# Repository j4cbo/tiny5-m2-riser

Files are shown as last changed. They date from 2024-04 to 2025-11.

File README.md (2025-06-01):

# Tiny5 M.2 Riser

This is a project I've been working on to create a custom riser board for Lenovo Tiny5
series (M920q/M920x/P330 Tiny) to support an additional two M.2 SSDs as well as a 10G Ethernet card.
It builds on badger707's excellent work investigating [PCIe bifurcation](https://github.com/badger707/m920q-pcie-bifurcation/)
and adding a [second M.2 slot](https://github.com/badger707/m920q-dual-NVME/) to these systems.

Fully loaded with this riser, an M920x can support four M.2 2280 M-key SSDs, as well as an additional PCI card,
a SATA boot SSD, and an M.2 2230 E-key module. It also provides a standard 12 volt fan header.

This works **only** with the M920q, M920x, and P330 Tiny. Other systems in the Tiny5 family do not support PCIe bifurcation.

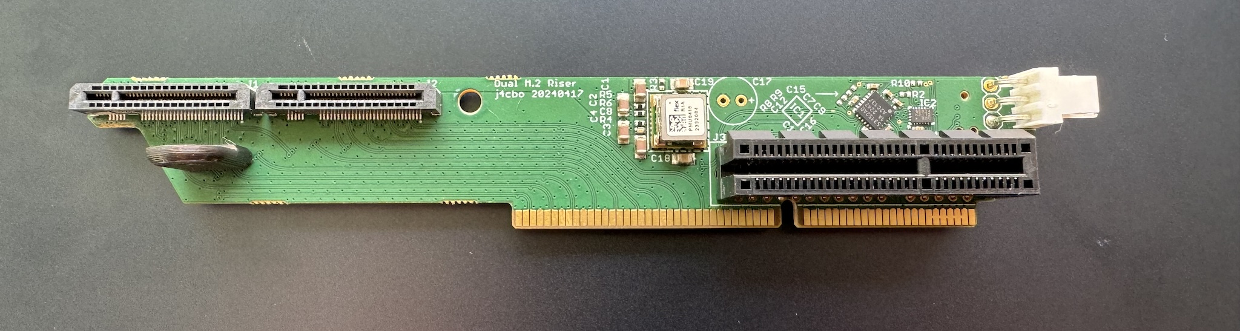
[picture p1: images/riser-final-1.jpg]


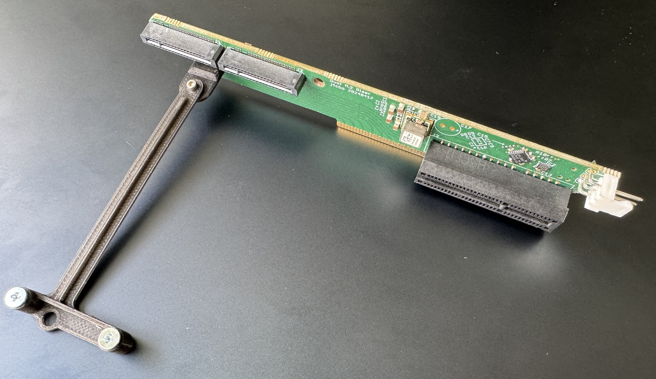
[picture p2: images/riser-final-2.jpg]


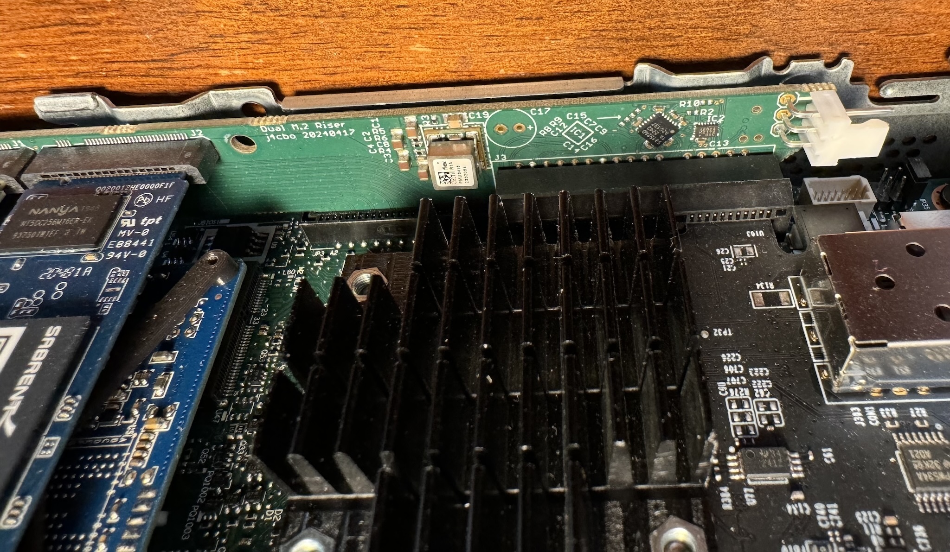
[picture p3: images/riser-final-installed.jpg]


Block diagram:
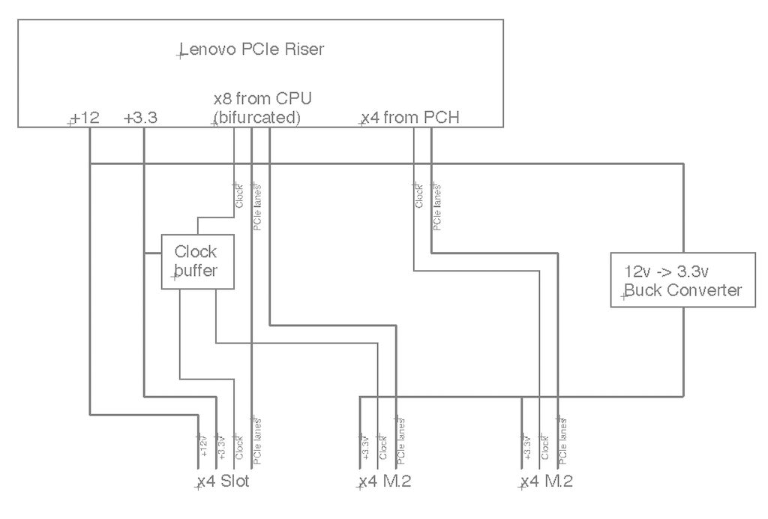
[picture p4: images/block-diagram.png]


According to the IQ3X0IL board schematics, the system +3V3 rail is rated for 9.74 amps, and is used for
various onboard components as well. A typical M.2 SSD is specified for 2.5 to 3.0 amps so four of them at
full load could exceed the power supply capacity. The riser board therefore uses a buck converter from
the +12V rail to avoid overloading the system +3V3 supply.

In addition to the power supply and clock buffer, a custom-programmed GreenPAK is used to handle
power sequencing and ancillary PCIe signals like PERST# and CLKREQ#.

As of 5/14/2024, I have a production batch of these and am now selling them, see issue #1.

Using this **requires soldering** two 0402 resistors on the motherboard to enable PCIe bifurcation.
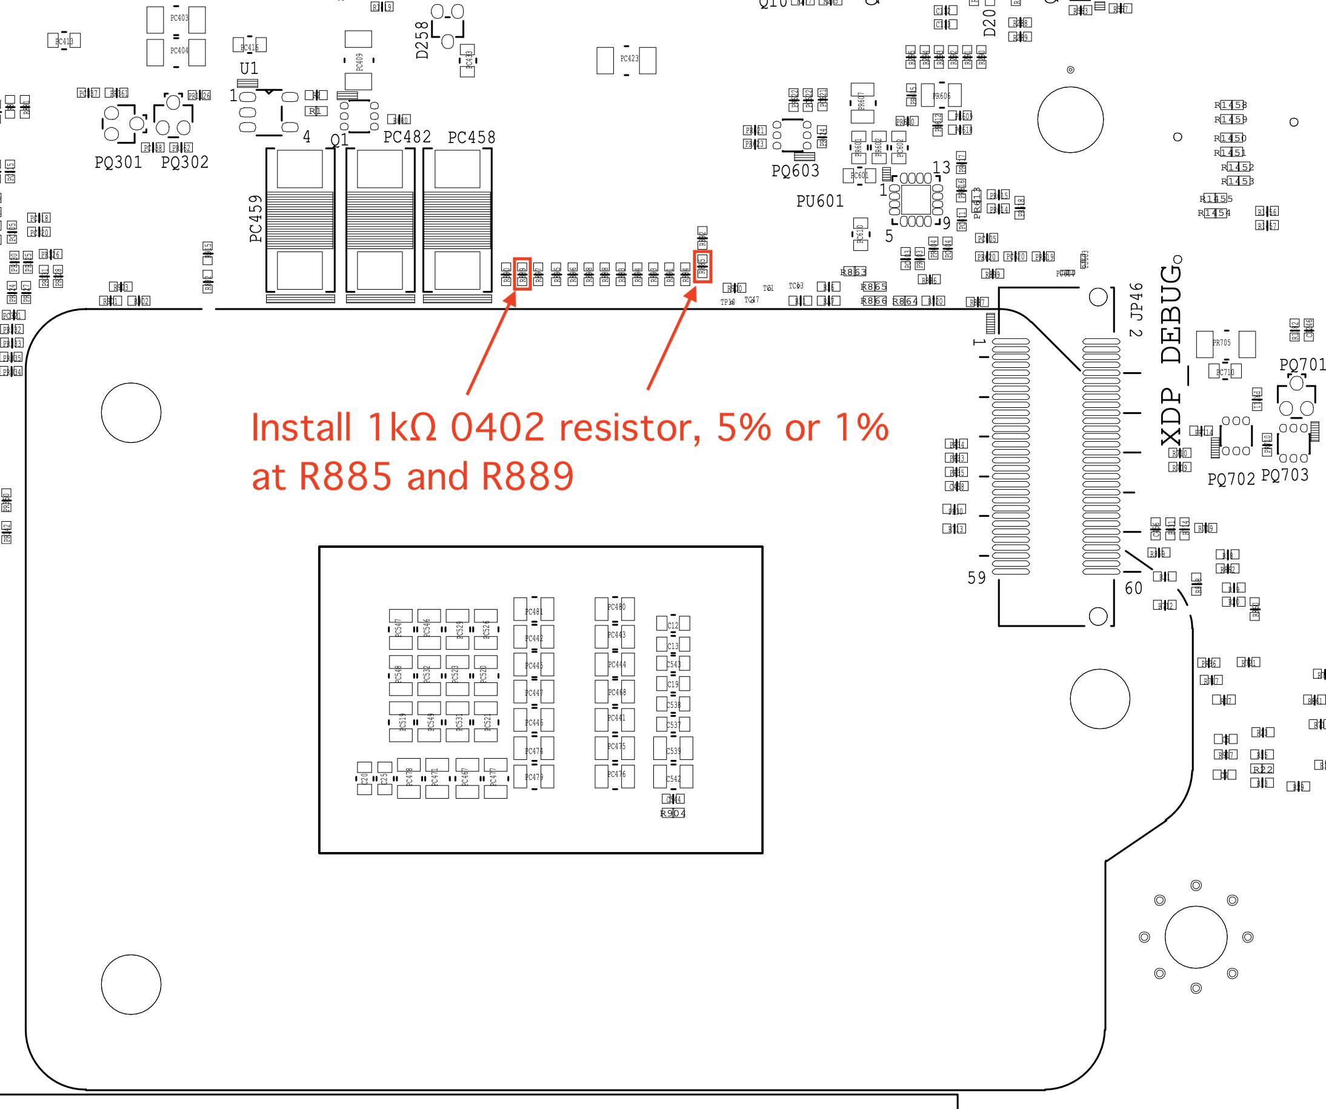
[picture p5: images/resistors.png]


## Mounting Bracket

There is also a mounting bracket to hold the additional M.2 drives in place. It replaces the WiFi antenna
support at the front of the case.

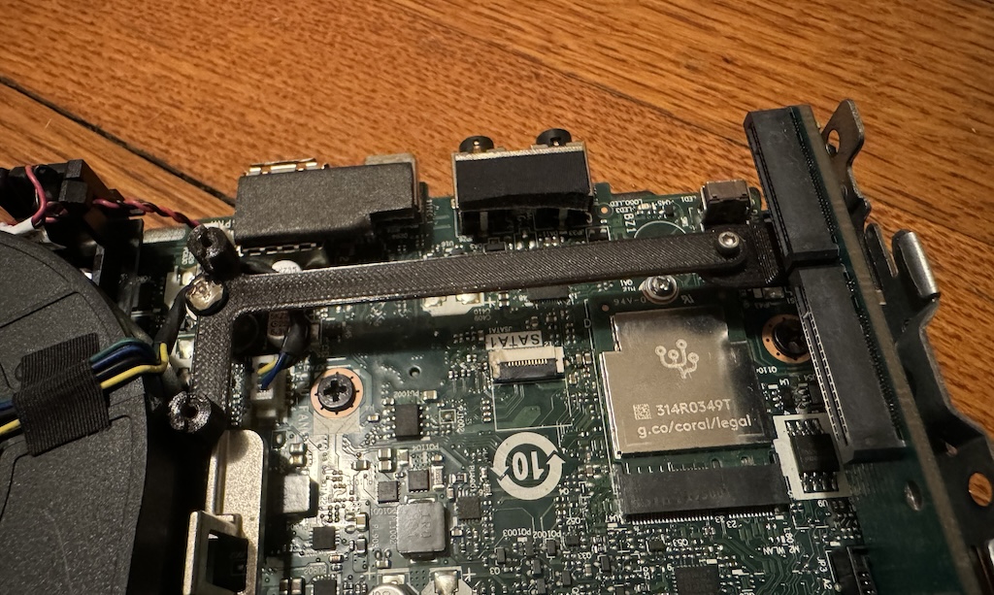
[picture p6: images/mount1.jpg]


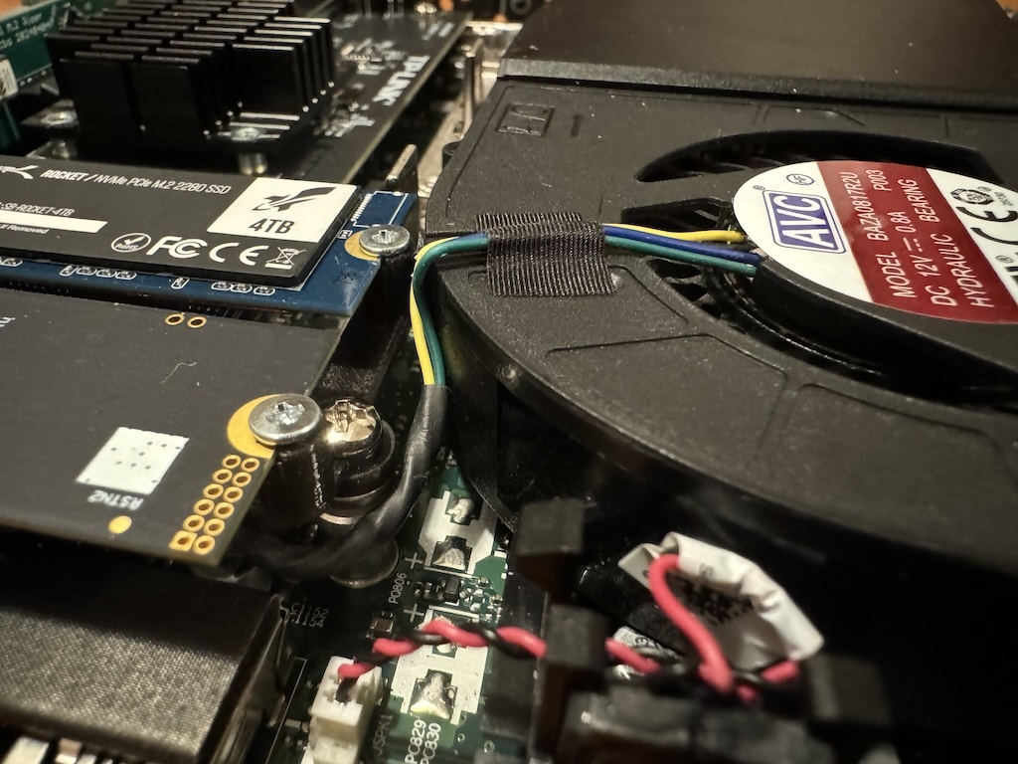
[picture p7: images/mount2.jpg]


## Disclaimer

This design is EXPERIMENTAL and provided WITHOUT WARRANTY. It has not been approved by Lenovo, the
FCC, or really anybody. I am not responsible if it breaks your computer, deletes your data, burns
down your house, or kicks your cat.

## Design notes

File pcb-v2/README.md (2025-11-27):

# Ordering Boards

The riser can be assembled by any PCB manufacturing contractor. I used [JLCPCB](https://jlcpcb.com/) and have optimized the parts list for their process. To order your own batch:

- Log in to your account (or create a new one, if you don't already have one).
- Upload `riser-v2.zip` with the "Add gerber file" box on the home page.
- Some properties of the PCB (4 layers, outside dimensions) will be auto-detected, but you will need to change several options:
  - Surface Finish: **ENIG**
  - Layer Stackup: **JLC04161H-7628** (this is critical for the PCIe bus to work!)
  - Impedance Control: **Yes**
    - Select +-10% option (Excel template is included in Gerber zip)
  - Mark on PCB: **Order Number (Specify Position)**
  - Gold Fingers: **Yes**
  - 30° finger chamfered: **No** 
- Check the "PCB Assembly" box and make sure these options are selected:
  - PCBA Type: **Standard** (Economic not available)
  - Assembly Side: **Top Side**
  - Edge Rails/Fiducials: **Added by JLCPCB**
  - Parts Selection: **By Customer**
  - PCBA Qty: although JLC will manufacture PCBs only in multiples of 5, you can choose to have them solder parts onto as few as 2 of them - but doing so usually doesn't save much money.
- Click "Next". Make sure the top side of the PCB is selected, and click "Next" again.
- Upload `riser-v2_top_bom.csv` and `riser-v2_top_cpl.csv`.
- At this point you should see a parts list showing which parts are in stock and which are out of stock. Most likely, the `SI53152-A01AGMR` clock buffer chip and `MDT350M01001VT` right-angle M.2 connector will be out of stock, so you'll need to use JLCPCB's global sourcing tool to order them. If any other parts are out of stock, note those as well.
- If parts are out of stock, you can click "next", choose "Do not place", and "next" again to see what the cost would be excluding the missing parts. Don't actually check out with missing parts, unless you're willing to buy and solder them yourself. If you're just getting an estimate, don't worry about the component placements being just right.
- Go to the [JLCPCB Parts Manager](https://jlcpcb.com/user-center/smtPrivateLibrary/myPartsLib) and click "Global Sourcing Parts".
  - For the clock buffer, search for either `SI53152-A01AGM` or `SI53152-A01AGMR` (these are equivalent parts). Find a supplier with an MOQ (minumum order quantity) less than the number of risers you're making and click "add".
  - Repeat for any other out-of-stock parts.
- Click "Parts Cart" on the left-hand sidebar and make sure "Global Sourcing Parts" near the top is selected. You should see the parts you added. Then check out. What you are doing in this step is paying JLCPCB to source and store those parts for your future order. It usually takes a few weeks for them to arrive, and you'll get an email when that happens.
- Once the parts you ordered are available, repeat the whole process from the top. **Make sure to choose the right Impedance Control and Layer Stackup options if you're starting over.**
- At the "Component Placements" step, click "Select all top parts" and use the arrow keys to move the parts so that they line up with the pads on the board. You can rotate parts 90 degrees at a time with the spacebar.
  - All the R, C, and L parts are symmetric - there's no such thing as the wrong way around.
  - The pins of J4 should be sticking off in space past the end of the board, away from all the other components.
  - Make sure the white circle on IC1 and IC2 is near the corresponding white circle on the PCB.
  - The "out" pin of Y1 should be on the top left side, near the white "Y1" text on the PCB.
  - The + side of D1 should be down towards the PCIe slot.
- Finally, click "save to cart" and check out.

If you use another manufacturer, give them the following PCB specifications:
- Controlled impedance
- Coplanar differential pair (on L1 referenced to L2, and on L4 referenced to L3) of 85 ohms nominal, +/- 10 ohms
- ENIG surface finish with gold fingers
- No chamfer

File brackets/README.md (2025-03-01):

These are the STL files for the dual M.2 riser. They can also be [exported directly from OnShape](https://cad.onshape.com/documents/99f2719df4fededdfde5e0b6/w/fa3fefc0be67ea79d0f2b093/e/995a9ee69cf62af61cb02c70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).

You will also need:
- Three M1.6 x 5mm screws
- Two M2 x 2.5mm screws, with large flat heads suitable for securing the M.2 SSDs

To assemble the risers:

1. Print one copy of each file (`m2-mount` [see options below], `pcb-angle`, `spacer`). I use PLA with the default PrusaSlicer settings, 0.1 mm layer height for `spacer` and 0.2mm for the other files.
2. Use an M1.6 screw to "pre-tap" each of the three holes in the pcb-angle part. This will make the rest of assembly much easier.
3. Using the `spacer` on the back of the PCB with the bridge portion away from the PCB, assemble `spacer` and `pcb-angle` as shown. It is important that the screw heads not come directly into contact with the PCB, because there are signal traces very close to the holes.
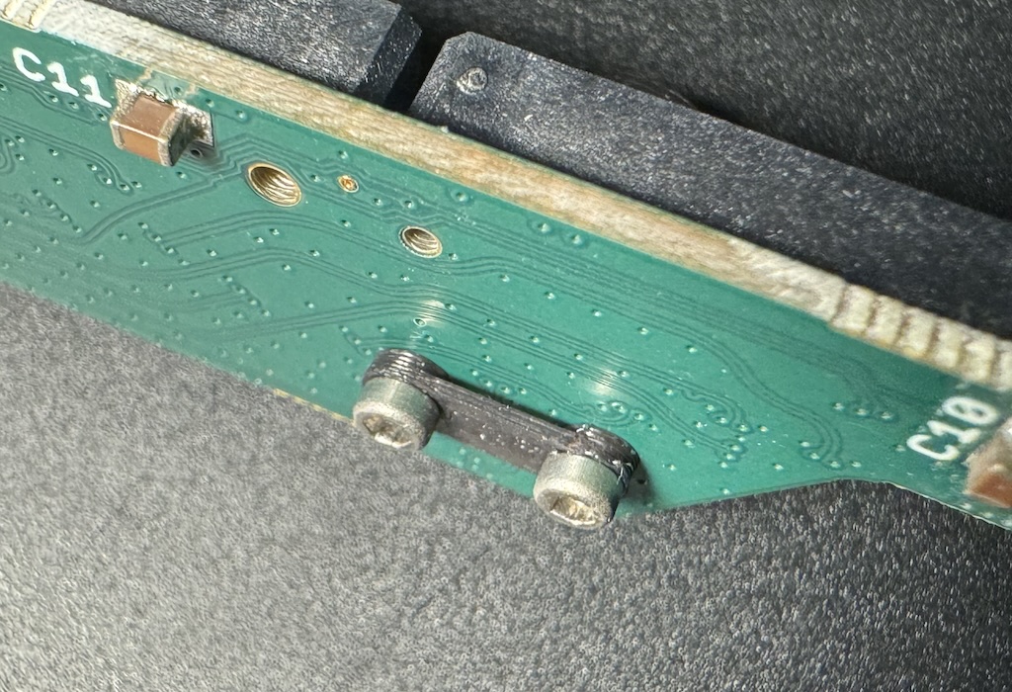
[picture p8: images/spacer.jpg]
   
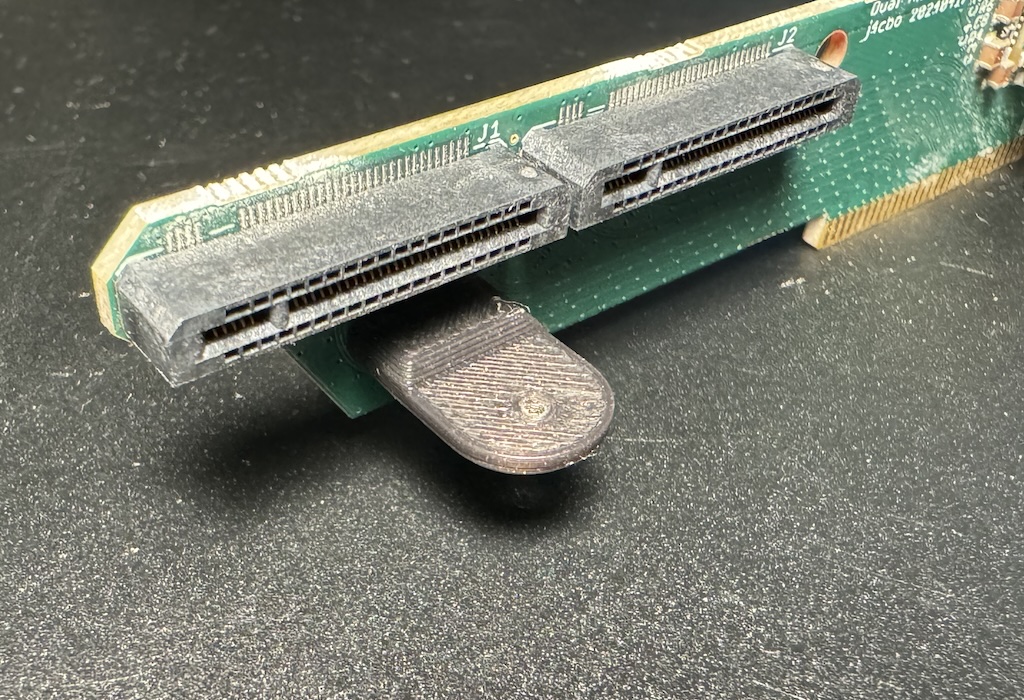
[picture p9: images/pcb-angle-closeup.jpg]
   
5. Attach `m2-mount` to the flat portion of `pcb-angle`.
   
5. Remove the internal WiFi bracket from your M920q and install the riser board assembly. Use the existing standoff and screw to retain the opposite end of the `pcb-angle` part.
6. Install the SSDs and PCIe card. Enjoy your extra storage!

### Mount Options

| STL-File | Option | Image |
| --- | --- | --- |
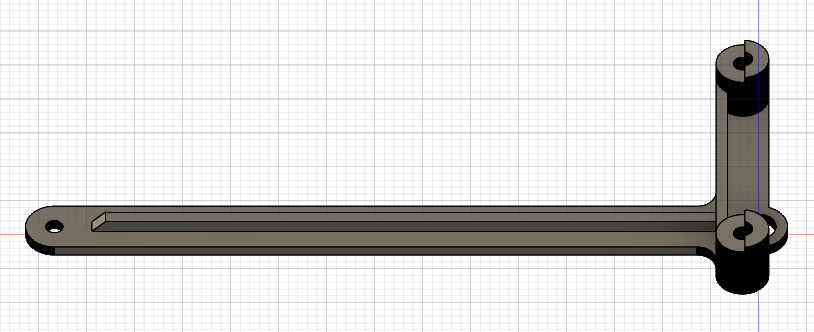
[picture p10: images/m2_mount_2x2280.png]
|`m2-mount`|2280 + 2280||
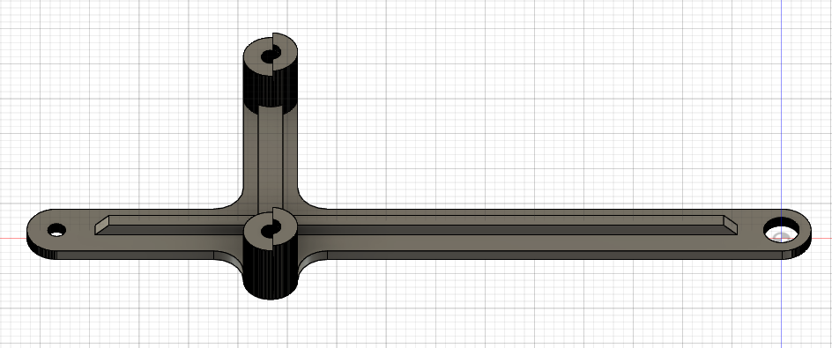
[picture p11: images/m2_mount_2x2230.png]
|`m2-mount_2x2230`|2230 + 2230||
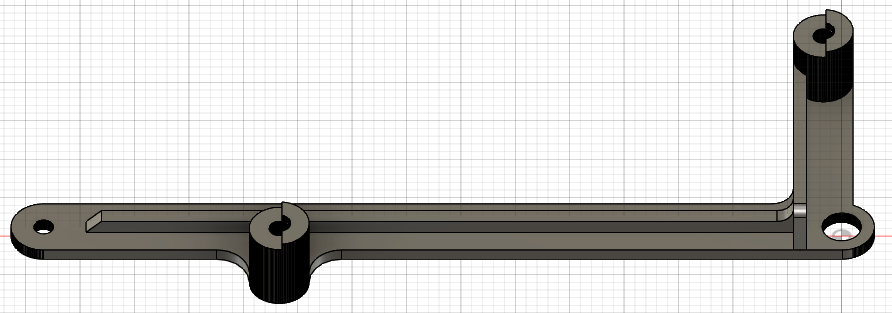
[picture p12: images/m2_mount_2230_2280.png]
|`m2-mount_2230_2280`|2280 + 2230||

**Example 2230+2280**
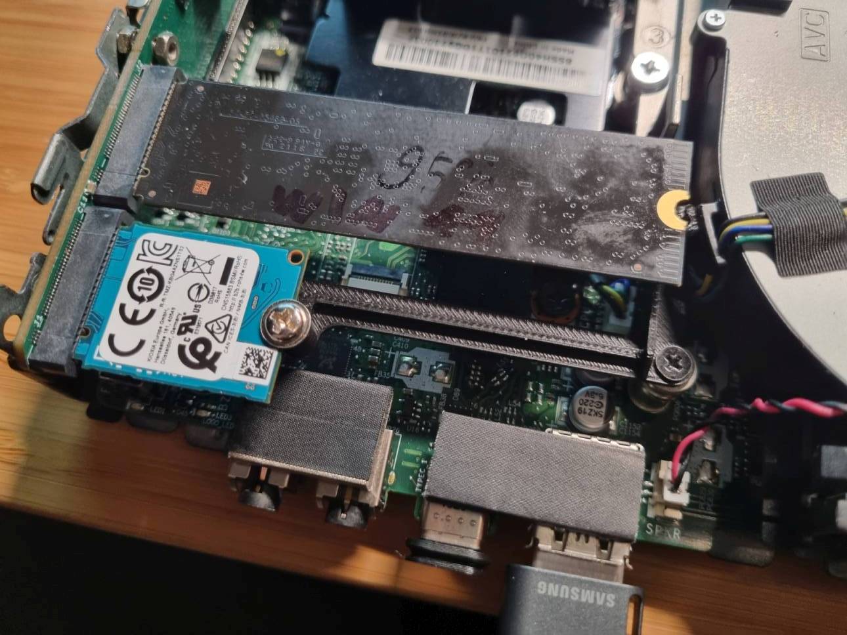
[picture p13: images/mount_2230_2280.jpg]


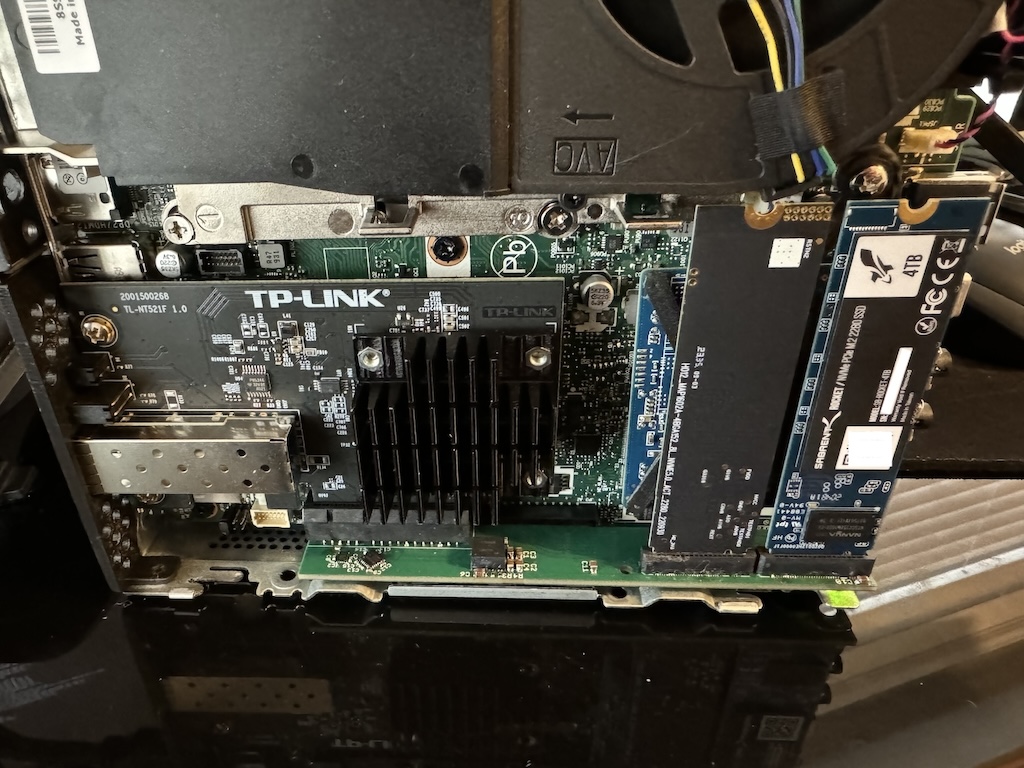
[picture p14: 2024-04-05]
images/prototype1.jpg

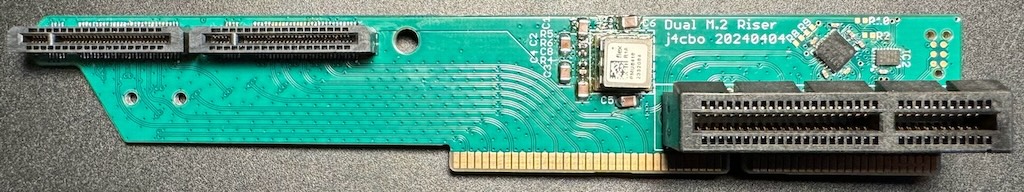
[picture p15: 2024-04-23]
images/prototype2.jpg

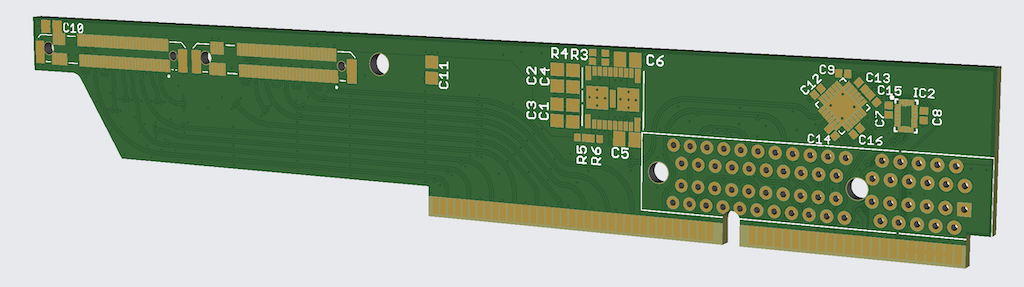
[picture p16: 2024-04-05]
images/prototype1-pcb.png

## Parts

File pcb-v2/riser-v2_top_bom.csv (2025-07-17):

Comment | Designator | Footprint | JLPCB Part #
0.1uF | C7 C9 C12 C13 C14 C15 C16 C20 | C0402 | C1525
1N5819 | D1 | SOD323-R | C191023
1uF | C1 | C0402 | C52923
2.2k | R3 R6 | R0402 | C25879
2N7002 | T1 | SOT23-3 | C8545
10k | R2 R5 R7 R8 | R0402 | C25744
10uF 10V | C10 C11 | C0603 | C19702
10uF 25V | C21 C22 C23 | C1206 | C13585
47uF 10V | C2 C3 C4 | C1206 | C96123
0022053031 | J4 | 1X03 | C706940
ECS-327KE-TR | Y1 | OSC_ECS-327KE-TR | C5280579
MDT350M01001VTEXT | J1 J2 | MDT350M01001VT_EXT | C722526
PCI-E-X4 | J3 | PCI-E-X4 | C2926855
SI53152-A01AGM | IC1 | QFN24_4X4_SIL | C2651396
TPS51386RJNR | IC2 | VREG_TPS51386RJNR | C22388893
XAL7070-182MEC | L1 | DFN750X725X700-2N | C3911679

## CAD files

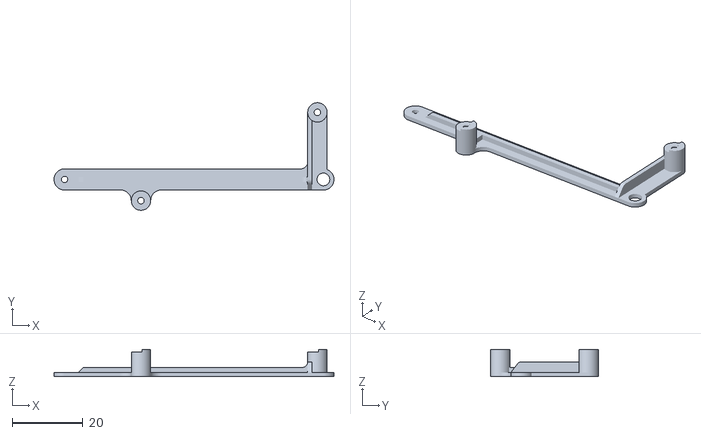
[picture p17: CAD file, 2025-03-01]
brackets/m2-mount_2230_2280.stl
79.4 x 30.5 x 7.70

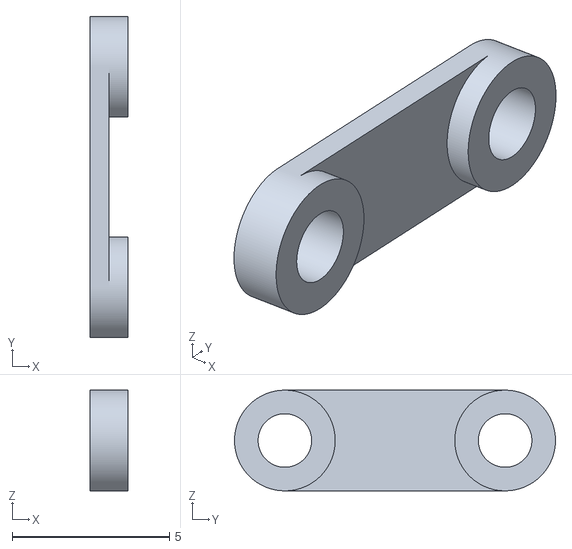
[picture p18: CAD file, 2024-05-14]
brackets/spacer.stl
1.20 x 10.2 x 3.20

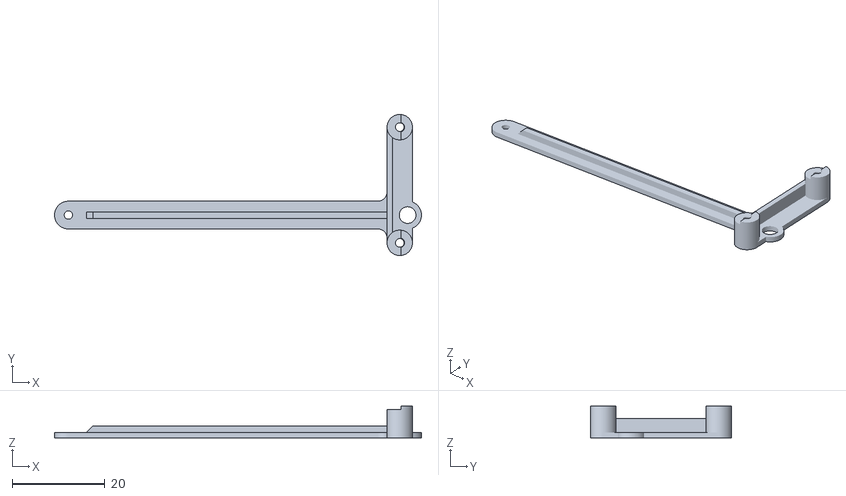
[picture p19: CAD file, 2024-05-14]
brackets/m2-mount.stl
79.4 x 30.5 x 6.90

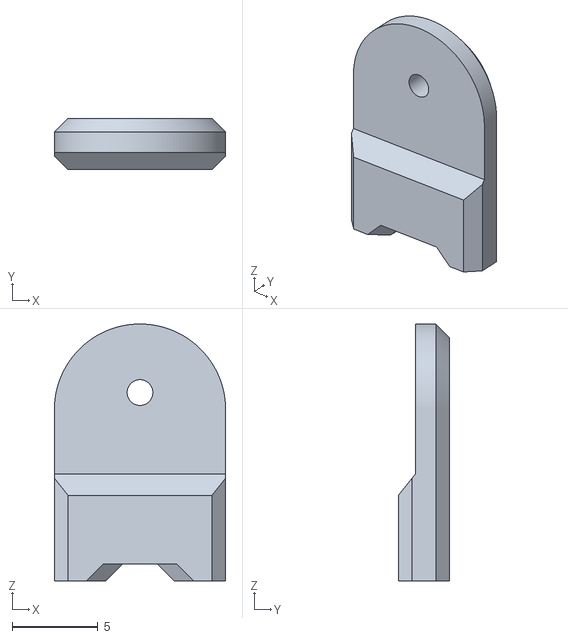
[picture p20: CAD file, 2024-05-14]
brackets/pcb-angle.stl
10.0 x 3.00 x 15.0

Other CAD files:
brackets/m2-mount_2x2230.stl

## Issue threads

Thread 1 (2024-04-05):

Group buy interest?

j4cbo, 2024-04-05:
A few people have mentioned interest in buying one of these so I'm starting a thread to discuss. Price will be $50 each plus shipping.

galvesribeiro, 2024-04-05:
Hello! I do want one. Sign me in! :)

kitor, 2024-04-06:
I'd build one myself so I'm interested in either bare pcbs or project files.

struthio, 2024-04-07:
hi, I am interested in final product or bare pcbs. I have also 2 questions:
1. When final price will be known ?
2. What is price for shipping ? I saw You are located in USA, so shipping to Europe might be pricey (compared to price of adapter).

marcojk, 2024-04-08:
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

Same here, possibly an Europe-based group buy could be set up.
Opening the design would be nice too!

systemerror-codenotfound, 2024-04-08:
Hi,
It would be possible to try an develop a version for the M910X ?

I'm part of a group here on spain that would be really interested im several parts

skruje, 2024-04-09:
I'd probably be in for 1-3 of these once you're satisfied with the prototypes, depending on the pricing.

Will the custom riser still require all the SMD soldering on the motherboard shown in badger707/m920q-dual-NVME?

Nice to haves for future revs:
- option for an x8 port for shorter cards like the AOC-STGN-I2S. Maybe a jumper to select x8x4 or x4x4x4. If not practical electrically, an x8 slot wired for x4, or just one with an ["open" end](https://upload.wikimedia.org/wikipedia/commons/a/a3/PCIe_J1900_SoC_ITX_Mainboard_IMG_1820.JPG) would be more flexible at similar cost.
- 12V (~0.1A) fan header for cooling hotter cards without additional soldering

kitor, 2024-04-09:
> Hi, It would be possible to try an develop a version for the M910X ?

@systemerror-codenotfound Why don't you start own issue instead of hijacking non-related one?

> Will the custom riser still require all the SMD soldering on the motherboard shown in [badger707/m920q-dual-NVME](https://github.com/badger707/m920q-dual-NVME/)?

@skruje No, you are confusing two different mods. This one requires bifurcation mod which is two resistors change from [badger707/m920q-pcie-bifurcation/issues/1]

If you use both, you can go crazy and have up to 6 NVME drives in this computer. One in existing slot, one in dual nvme mod, three using riser we discuss here and one extra in WiFi slot (but that will work as PCIe x1) :)

> option for an x8 port for shorter cards like the AOC-STGN-I2S. Maybe a jumper to select x8x4 or x4x4x4.

This was already answered in badger707 thread. It is impossible, not impractical, due to a few factors:

* you can't "switch" where 4 pairs of signals go with a single jumper
  * switching between bifurcated and non-bifurcated slot is done via modding the motherboard - you change cpu configuration resistors for that.
  * in modified state, PCIe lanes are out of order and this riser corrects for that
  * thus in unmodified (x8) state lanes would be out of order again and nothing would work
* you could try wire up signals to both one of NVME m.2 slots and PCIe slot, but this fails quickly:
  * out of order problem from above
  * even if not, signal reflections would be the issue (considering lanes connected to both slots)
  * and in that hypothetical / impossible situation you would still need to select x8+m.2 or x4 + dual m.2 by soldering proper slots into your riser and selecting resistors on the board.

Open end slot seems a good idea on the first glance (but you can also mod your slot very easily with craft knife). However from the photos I'm not sure if x8 card would even fit - I'm under impression that first m.2 slot would interfere anyway.

j4cbo, 2024-04-09:
The way I think of it, https://github.com/badger707/m920q-dual-NVME turns an m920q into roughly an m920x, which has two onboard M.2 connectors for NVMe SSDs. Then my board in conjunction with the two resistors changed in https://github.com/badger707/m920q-pcie-bifurcation adds two more M.2s (one off the PCH, one off the bifurcated CPU port) and provides a PCIe x4 slot. As @kitor says, if you aren’t using the slot for a network card, then (with a PCIe x4 to M.2 board) you could add another SSD there, and if you aren't using the WiFi M.2 you could (with an A+E-key to M-key adapter) add yet another SSD there, albeit with only one PCIe lane.

There's about 10mm vertically between the M.2 connectors and the x4 slot on my board, so a PCIe card that extends under the M.2 SSDs would be fine as long as it didn't have a large heatsink.

j4cbo, 2024-04-10:
Update: price for the first batch will be $70 USD each plus shipping, and I expect them to be available in mid-May. There will also be a 12V fan header on the board with the standard 3-pin PC fan pinout. This is for m920q/m920x only. The m720q doesn't support bifurcation, and the m910 series has a different pinout and lacks the additional 4 PCH lanes on the socket. (A single-M.2 m720q variant is in the works, though.)

Shipping will be about $5 within the US. Internationally, slow shipping (1-4 weeks) is about $25, or by UPS about $40. It might make sense for me to ship a bunch to someone in Europe for further distribution from there.

skruje, 2024-04-10:
Love that @j4cbo managed to get a fan header in there. I'm out for now; hoping we can find a more economical way to deliver to Canada for future batches. Any chance the design will be open sourced?

j4cbo, 2024-04-10:
Canada shipping is cheaper than Europe - I edited the post above with those prices and quantity discounts. I'm not opposed to open-sourcing the design but, selfishly, I'd like to make back what I spent on the first batch first :)

chocmake, 2024-04-11:
> This is for m920q/m920x only. The m720q doesn't support bifurcation

Just to clarify, badger's bifurcation repo states compatibility for M720q. Is something different for this riser or am I missing something?

j4cbo, 2024-04-11:
> Just to clarify, badger's bifurcation repo states compatibility for M720q. Is something different for this riser or am I missing something?

It's mentioned in the README, but there's a good argument as to why bifurcation wouldn't work on the m720q here: https://github.com/badger707/m920q-pcie-bifurcation/issues/2#issuecomment-1835940720

The m720q does still have the extra 4 lanes from the PCH, though, which should support a single M.2.

j4cbo, 2024-04-18:
I have one prototype available which I'm offering for free (within the US) if anyone wants to beta test. It lacks the fan header and open-back PCIe slot that the production ones will have (probably a month out), and it's not pretty, but I've tested in my own server and it is working well. My email is on my Github profile.

galvesribeiro, 2024-04-18:
Would test for you but I'm in Brazil :P

j4cbo, 2024-04-19:
Update: I've placed the production order :) I was able to get the price down to $50. The production boards will include an open-backed PCIe slot and a 12V fan header, and will be ready in about a month.

galvesribeiro, 2024-04-19:
Looking forward for it :)

struthio, 2024-04-19:
@j4cbo $50 for M920Q one ? (2x NVME + 1xPCIe for Ethernet) ? If Yes then I even consider getting 2.
Are You taking any pre-orders ?

galvesribeiro, 2024-04-19:
Yeah, rephrasing, I want 2 as well 😄

@j4cbo if you can send email and/or PayPal/Wise or whatever way you decide to be paid, we can put the pre-order ahead.

j4cbo, 2024-04-21:
To pre-order, send me an email - my email address is shown on my main Github profile :)

galvesribeiro, 2024-04-21:
Done :shipit:

struthio, 2024-04-22:
> I'm not opposed to open-sourcing the design but, selfishly, I'd like to make back what I spent on the first batch first :)

Maybe then, add project files as a documentation to bought boards or something like that ?

j4cbo, 2024-04-29:
Just an update here, the manufacturer has finished fabricating the bare PCBs and is now preparing for assembly. Still looking like I'll have them by the end of May.

mdronald, 2024-05-01:
> Just an update here, the manufacturer has finished fabricating the bare PCBs and is now preparing for assembly. Still looking like I'll have them by the end of May.

I'm interested in buying one or two but I've the m920q model. Would I have to mod it using [badger707](https://github.com/badger707/m920q-dual-NVME/commits?author=badger707) guide to work as a m920x before using your riser?
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
j4cbo, 2024-06-14:
Thanks for all the info! In my own system I'm currently running TrueNAS SCALE on bare metal, but I had been thinking of putting a Proxmox layer underneath. (TrueNAS works well enough as a VM host but Proxmox is much more powerful.) It's interesting that there's an interaction between passthrough and bifurcation, not terribly surprising but it seems like it "should" work.

I'm now sold out of the first batch of 20 boards! I'll ask the manufacturer about pricing for a follow-up batch. Anyone else who's interested in buying one, please let me know.

Go0oSer, 2024-06-19:
Are these still available?  Id be interested in 2 if so.

j4cbo, 2024-06-20:
Update: I've ordered more boards! :) I'll reach out to everyone who's contacted me once they're ready to ship.

joseal, 2024-06-24:
Hi @j4cbo, please count with me for one more board to EU. If there is anyone else interested in EU, I don't mind to join for a group buy.

thank you!

marcojk, 2024-06-24:
> > I wonder where @j4cbo ordered the first batch. Maybe it would be just cheaper to order a second batch directly to someone in EU ... assuming there's enough interest of course.
>
> This is the option i was referring to. Collect the order, pay to j4cbo, order shipped directly to europe and from here we will manage somehow :)

I'd be interested in 2 boards, and I still believe this could me an interesting alternative...

AndrewL82, 2024-06-26:
Hey, I'd be interested in buying 2 if shipping to Australia isn't too much :)

su-thomas, 2024-06-27:
> Hey, I'd be interested in buying 2 if shipping to Australia isn't too much :)

@AndrewL82 I'm also interested in Australia, perhaps we can bundle shipping to save on costs

randlor, 2024-07-28:
Hi, in the UK and interested in one. Thanks.

wouterbouvy, 2024-08-02:
Awesome work @j4cbo! I would be interested in buying 3 or 6 of your risers once your new batch arrives. Shipment to the EU.

j4cbo, 2024-08-02:
The new batch is here! :) Send me an email if you haven't already.

lmbacelar, 2024-08-26:
Hi. Are  you still selling these?
I am interested in +3 boards delivered in EU.

mvnixon, 2024-08-27:
Hi, I sent you an email, not sure if you received it, I am after 2 delivered to the EU. Thanks

j4cbo, 2024-08-27:
@lmbacelar - yep, still available! Send me an email, my address is on my Github profile.
@mvnixon - just replied to your email

j4cbo, 2025-01-18:
Closing this now. I'm not planning on making any more, but all the files necessary for someone else to order a batch from JLCPCB are in the repository - happy to walk anyone through the process if they're interested in doing so.

evil2k2, 2025-01-18:
> Closing this now. I'm not planning on making any more, but all the files necessary for someone else to order a batch from JLCPCB are in the repository - happy to walk anyone through the process if they're interested in doing so.

Can you give some information about manufacturing?
And also how you programmed the green pack.
Thanks for the great work
Do you plan to work in newer machines like p350 or 360/P3 tiny?

j4cbo, 2025-01-18:
> Can you give some information about manufacturing? And also how you programmed the green pack. Thanks for the great work Do you plan to work in newer machines like p350 or 360/P3 tiny?

I uploaded a description of how to order here: https://github.com/j4cbo/tiny5-m2-riser/tree/main/pcb-v2

The new rev doesn't require any programming, but for the old one, I used an SLG4DVKDIP dev board and a Tag-Connect cable to flash the Greenpak parts.

No plans to design for newer machines, since the M920 is the only one I have :)

Closed 2025-01-18.

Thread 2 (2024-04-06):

Why you use a buck converter and aren't the nvme drives overheating??

systemerror-codenotfound, 2024-04-06:
Just take 3.3V from the X4 slot and use it

Also, those drives need some cooling no?
aren't them overheating?

I have a 3d printable lid that can use a 120mm fan but it's pretty big
https://www.printables.com/es/model/603074-lenovo-tiny-m910q-top-cover-mods

galvesribeiro, 2024-04-06:
He already explained why he did that [here](https://github.com/badger707/m920q-pcie-bifurcation/issues/1#issuecomment-2035056651).

j4cbo, 2024-04-06:
I've added some current numbers to the README. As for temperature, the highest I saw during an extended ZFS resilver was 67°C which is within spec.

Closed 2024-04-06.

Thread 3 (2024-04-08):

Adapt this mod to M910X

systemerror-codenotfound, 2024-04-08:
The diagram for M910X should be similar to this, this is from a M710Q as i couldn't find one for the M910X
https://images.boosty.to/image/e28a63ee-ad04-4562-828a-b6a58697e4db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

And this is the one for the M920Q
https://cxema.su/_sh/37/3745.jpg

and the Q270 in m910x chipset support the same bifurcation as the M920q

https://www.intel.la/content/www/xl/es/products/sku/98088/intel-q270-chipset/specifications.html

1x16 or 2x8 or 1x8+2x4

If i'n not wrong, right now you are getting 3 x4 pci ports from the actual PCI, 2 by bifurcating the PCI in 2 x4 and one x4 from the chipset
As per other comment in the @badger707 repo the pads are almost exactly the same and somebody actually tried to bifurcate it and it appear as 2 x4 lines and 1 x4 line, so the bifurcation on the CPU side works

j4cbo, 2024-04-09:
So, the main difference between my mod and https://github.com/badger707/m920q-pcie-bifurcation is that the M720/M920 series route an additional 4 lanes from the PCH to the riser slot, in addition to the 8 lanes from the CPU. Looking at the schematics for the IQ270IH1 (m710/m910/P320), it looks like the pinout is different and the extra 4 lanes aren't there:

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

I think https://github.com/badger707/m920q-pcie-bifurcation/issues/3 is the issue describing what you're looking for?

systemerror-codenotfound, 2024-04-26:
Okay,
it's working on the m910x, i have to make some tests but i'm able to use both nvme's

The weird part is that i'm seeing another x8 pci bus

zzs95, 2024-04-26:
> the original comment was made by @zzs95

> it's working on the m910x, i have to make some tests but i'm able to use both nvme's

Thank you very much for your verification. I wondered if there was something wrong with my machine, so that I didn't make it.

I am more inclined to think that there is no 4x pcie from PCH on the m910x machine, because there is no 4x riser in the [accessory library](https://pcsupport.lenovo.com/us/en/products/desktops-and-all-in-ones/thinkcentre-m-series-desktops/thinkcentre-m910x/10my/parts/display/compatible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) Later models m920x and p340 tiny (m90q gen1) have this accessory.

m920x (01AJ929):
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

m90q gen1(5C50W00876):
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

j4cbo, 2024-04-26:
I think this discussion probably belongs over on https://github.com/badger707/m920q-pcie-bifurcation ? The riser I designed to allow putting three separate PCIe devices (two M.2s and an x4 slot) isn't possible because there's no routing from the PCH to the expansion slot - but bifurcation _does_ work on the 910 series.

galvesribeiro, 2024-04-26:
> Okay, it's working on the m910x, i have to make some tests but i'm able to use both nvme's
>
> The weird part is that i'm seeing another x8 pci bus

After doing the PCIe bifurcation mode, add the "official" riser, it got me an extra x8 controller as well (x16, x8, x4):

```
[root@yoda:~] lspci
0000:00:00.0 Host bridge: Intel Corporation 8th Gen Core Processor Host Bridge/DRAM Registers
0000:00:01.0 PCI bridge: Intel Corporation 6th-10th Gen Core Processor PCIe Controller (x16)
0000:00:01.1 PCI bridge: Intel Corporation Xeon E3-1200 v5/E3-1500 v5/6th Gen Core Processor PCIe Controller (x8)
0000:00:01.2 PCI bridge: Intel Corporation Xeon E3-1200 v5/E3-1500 v5/6th Gen Core Processor PCIe Controller (x4)
0000:00:02.0 VGA compatible controller: Intel Corporation CoffeeLake-S GT2 [UHD Graphics 630]
0000:00:08.0 System peripheral: Intel Corporation Xeon E3-1200 v5/v6 / E3-1500 v5 / 6th/7th/8th Gen Core Processor Gaussian Mixture Model
0000:00:14.0 USB controller: Intel Corporation Cannon Lake PCH USB 3.1 xHCI Host Controller
0000:00:14.2 RAM memory: Intel Corporation Cannon Lake PCH Shared SRAM
0000:00:16.0 Communication controller: Intel Corporation Cannon Lake PCH HECI Controller
0000:00:16.3 Serial controller: Intel Corporation Cannon Lake PCH Active Management Technology - SOL
0000:00:17.0 SATA controller: Intel Corporation Cannon Lake PCH-H AHCI Controller
0000:00:1b.0 PCI bridge: Intel Corporation Cannon Lake PCH PCI Express Root Port #17
0000:00:1b.4 PCI bridge: Intel Corporation Cannon Lake PCH PCI Express Root Port #21
0000:00:1c.0 PCI bridge: Intel Corporation Cannon Lake PCH PCI Express Root Port #6
0000:00:1f.0 ISA bridge: Intel Corporation Q370 Chipset LPC/eSPI Controller
0000:00:1f.3 Audio device: Intel Corporation Cannon Lake PCH cAVS
0000:00:1f.4 SMBus: Intel Corporation Cannon Lake PCH SMBus Controller
0000:00:1f.5 Serial bus controller: Intel Corporation Cannon Lake PCH SPI Controller
0000:00:1f.6 Ethernet controller: Intel Corporation Ethernet Connection (7) I219-LM
0000:02:00.0 Non-Volatile memory controller: Samsung Electronics Co Ltd NVMe SSD Controller PM9A1/PM9A3/980PRO
0000:03:00.0 Non-Volatile memory controller: Samsung Electronics Co Ltd NVMe SSD Controller PM9A1/PM9A3/980PRO
0000:04:00.0 Non-Volatile memory controller: Samsung Electronics Co Ltd NVMe SSD Controller PM9A1/PM9A3/980PRO
0000:05:00.0 Non-Volatile memory controller: Samsung Electronics Co Ltd NVMe SSD Controller PM9A1/PM9A3/980PRO
0000:06:00.0 Non-Volatile memory controller: Phison Electronics Corporation PS5013 E13 NVMe Controller
```

With that, I can put the two NVMe M.2 there and it just work. As you can see on `lspci` I have 4 Samsung 980 PRO there and they all work just fine (The Phison is a 2230 M.2 NVMe on the Wifi slot).

With @j4cbo Riser I will be able to use the other extra 4 lanes from the PCH and use along with the two M.2 a dual 10G NIC.

But yeah, you should go post on the other repo where you can get more help about the PCIe mod.

Closed 2024-05-03.

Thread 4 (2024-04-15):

[Suggestion] Use PCIe x16 connector

galvesribeiro, 2024-04-15:
On the prototype picture I see a x4 connector for the PCIe card.

Would it be possible to use a x16 connector with only x4 wired? The reason I'm asking is so we can easily use bigger cards using the same riser.

I know we can use an open-ended PCIe connector but those are harder to find for manufacture as they are not safer because leave the card connections "out".

I hope you consider the suggestion.

Thanks!

j4cbo, 2024-04-15:
An x16 connector won't fit because the space where the pins would go is needed for the signal traces to the M.2 connectors. However, I think I can source an open-back connector...

galvesribeiro, 2024-04-15:
Ok. Duck tape on the open connectors it is 😄

j4cbo, 2024-04-15:
If you want it to look nice and professional, pick up some Kapton tape :)

Closed 2024-04-15.

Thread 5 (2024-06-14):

Is this compatible with the P330 Tiny?

rohankapoorcom, 2024-06-14:
Do you know if this will work with the P330 tiny? My understanding is that the P330 tiny is close to the M920x since it has dual NVMe slots on the board already.

j4cbo, 2024-06-14:
I haven't tried one but I would expect so - it's the same IQ3X0IL motherboard and Q370 chipset as the M920x/M920q.

rohankapoorcom, 2024-06-17:
Cool - if you do another batch, I would be interested in picking up a few of them (at least 1, up to 3 or 4 assuming it works out with the P330).

CodyBohn, 2025-07-17:
I would also be interested in multiple from another batch

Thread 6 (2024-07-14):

Showcase riser working

galvesribeiro, 2024-07-14:
I just wanna share with others that I have full success using this riser.

I have 4x Samsung 980 Pro 2TB (two in the riser itself and two in the back), one M.2 on the Wifi slot (Phison on the screenshot) and a dual 25Gb Mellanox Connect-X 4 NIC, and another SATA SSD.

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

Thanks @j4cbo for the amazing work!

galvesribeiro, 2024-10-15:
> @galvesribeiro, were you get the full bandwidth for the dual 25GB with all NVMe in use?

Good question. I tested with only 1x 25GB connected and I got full bandwidth but never tried saturate both. Right now the machine is shutdown as I moved and have reassembled my lab yet. I'll do the test later on and report back.

ilium007, 2025-07-15:
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

Have you git any pics of how this is all fitted inside the case?

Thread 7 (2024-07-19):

Passthrough compatible version

fajeczek00, 2024-07-19:
As stated in the group buy when passing through only one of the bifrucated ports on proxmox the host doesn't enter proper c-states.
Would it be possible to create a PCB revision with all 8 bifrucated lanes going into 2 m.2 ports and PCH lanes going into the regular X4 slot ?

In that scenario if bios allows the bifrucated slots to boot it would be possible to use 2 bifrucated slots for a RAID 1 proxmox installation mitigating  passthrough sleep issues, leaving all the other slots to be used for various passthrough configs

j4cbo, 2024-08-10:
In theory, yes. The issue is geometry - the X4 slot is right up against the card edge connector, so there's nowhere to put the traces. Rearranging the connections that way would require going to a 6 or 8 layer PCB, adding significant cost (and requiring me to get different PCB layout software). So it's not on my to-do list, sorry :(

wrobelda, 2025-06-10:
Well, I just reported another issue closely related to to what @fajeczek00 suggests: https://github.com/j4cbo/tiny5-m2-riser/issues/19

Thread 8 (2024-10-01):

Any PCB left?

Jatsekku, 2024-10-01:
@j4cbo Amazing project!
Do you have any PCBs left or planing another round of ordering?
I'd be interested in one ;)

asche77, 2024-10-01:
If there is EU shipping, interested as well...

j4cbo, 2024-10-02:
I have 3 more assembled units available (and a bunch of bare PCBs, but that would be a big soldering project) - send me an email, my address is on my Github profile. I'm asking $55 USD each, and shipping is about $20 to most of the world or $5 within the US.

dionorgua, 2024-10-02:
I also want to get one in EU (Poland).

j4cbo, 2024-10-05:
Sorry, I'm all out now. I'm working on a new batch and I'll get back to everyone who's emailed me when I have them in stock again.

j4cbo, 2024-11-01:
I just received a new batch. If I haven't replied to your email please ping me again :)

sherbibv, 2024-11-17:
I'm interested, but I am not sure if I need the bifurcation mod even if I don't use the other pcie slot. I would like it just for the extra 2 m.2 ssds.

snzsnz, 2025-03-20:
Are you still selling these? Price shipped to NZ?

j4cbo, 2025-03-20:
I'm all out, but user evil2k2 is doing a build in Germany: https://github.com/j4cbo/tiny5-m2-riser/issues/11

mr4lexndr, 2025-08-13:
Hi All,

I have made a **batch of boards**.
📟  They are **available [here](https://www.tindie.com/products/letbco/pcie-riser-2x-nvme-x4-for-lenovo-tiny-m920m720/)**
📦 I ship them from the UK and the EU.

🔩 As an add-on, you can also obtain all the necessary **fasteners and brackets**.

Closed 2025-03-20.

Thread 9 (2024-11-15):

About the chip slg46824

CharlieYu4994, 2024-11-15:
I found that the SLG46824 is a programmable matrix and all the control signals are routed to this chip. Do I need to program it in order to use it? If so, how should I program it?

j4cbo, 2024-11-16:
The configuration file is in the repository, at `pcb/riser-greenpak.gp6`; I use a SLG4DVKDIP board to program it.

I'm working on a new rev of the board that will eliminate the GreenPAK part to make it easier to manufacture.

Chuckame, 2025-01-11:
@j4cbo did you succeed to eliminate the greenpak need?

j4cbo, 2025-01-18:
I did! Just uploaded, under `pcb-v2/` in the repository.

Closed 2025-01-18.

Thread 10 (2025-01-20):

Is this plug & play?

phere-x, 2025-01-20:
I'm new to this side of Tiny's entirely so forgive me for the novice questions.

I'm assuming it requires no soldering on the board or mods done by me? I came from https://github.com/a-little-wifi/Tinyriser first and it mentioned it should work by just plugging it in, is it the same for this? This seems the same, save for a nifty fan header it has but there's no instructions for ordering your own like the awesome guide j4cbo wrote out for us https://github.com/j4cbo/tiny5-m2-riser/tree/main/pcb-v2

Or if anyone's getting/had it done in the UK, anyone willing to help others out?

chocmake, 2025-01-21:
> I'm assuming it requires no soldering on the board or mods done by me?
Per the readme it requires soldering two 0402 resistors, on the underside of the motherboard. The riser by a-little-wifi's was unique in that it no mods were required.

j4cbo, 2025-01-21:
Yep, exactly.

The motherboard header has two separate PCIe interfaces: 8 lanes to the CPU, and 4 lanes to the PCH. Lenovo's 01AJ940 uses the CPU interface, and the 01AJ929 uses the PCH interface. I'm not sure why they did it this way but I suspect that the Thunderbolt addon has to be connected to the PCH, while the CPU interface is higher-bandwidth and better for a GPU.

The riser by a-little-wifi routes the x8 CPU interface directly to a PCIe slot, and the x4 PCH interface to an M.2 connector. Mine  instead splits the x8 CPU interface, routing half of it to an x4 PCIe slot and the other half to a second M.2 (and lane-reverses both of them). That allows for an extra SSD while still being able to fit a 10G Ethernet card in the x4 slot. But it also means bifurcating the x8 PCIe link to the CPU, which is the part that requires soldering and doesn't work with the M720q.

phere-x, 2025-01-26:
Really appreciate the responses & clarifications! I was really eager to try it out but soldering skills let alone the equipment is something I don't have to be attempting badger's soldering bifurcation.

May be a lot to ask, but any idea of how to get a hold of my own a-little-wifi's part? I only ever came across this from [tindie](https://www.tindie.com/products/crimier/tinyriser-a-better-lenovo-tiny-pc-riser/) but the seller is away & some poor reviews here n there. I've never used this site either. Not sure if anyone's doing anything on forum's but I couldn't find anything using google & some keywords.

evil2k2, 2025-01-26:
> Really appreciate the responses & clarifications! I was really eager to try it out but soldering skills let alone the equipment is something I don't have to be attempting badger's soldering bifurcation.
>
> May be a lot to ask, but any idea of how to get a hold of my own a-little-wifi's part? I only ever came across this from [tindie](https://www.tindie.com/products/crimier/tinyriser-a-better-lenovo-tiny-pc-riser/) but the seller is away & some poor reviews here n there. I've never used this site either. Not sure if anyone's doing anything on forum's but I couldn't find anything using google & some keywords.

For soldering the resistors you can ask my friend @AcidzDev (Discord acidz) also UK.
For the riser from @a-little-wifi's ask him on his repo.

maldworth, 2025-03-08:
> That allows for an extra SSD while still being able to fit a 10G Ethernet card in the x4 slot

If I have a m720q, could I use your riser, and I don't bother soldering the 2 resistors (because bifurcation doesn't work on m720q)? Then I would just get one of the nvme slots working, and then I'd get the pcie slot with just x4? So essentially a solderless option?

j4cbo, 2025-03-10:
The issue is the lane-reversal part. The Intel CPU in these systems actually has a 16-lane PCIe interface, but the Lenovo motherboard only routes lanes 0-7 to the riser. The CPU allows the port to be set up as x16 (lanes 0-15), x8+x8 (lanes 0-7 + 8-15), or x8+x4+x4 (lanes 0-7, 8-11, and 12-15). Fortunately there's also a lane-reversal feature in the CPU, which swaps the order of the lanes, _including_ how they're bifurcated - enabling both bifurcation and lane reversal means lanes 3-0 (in reverse order) form one logical port, and lanes 7-4 (in reverse order) form a second logical port. My riser then routes the traces so as to swap the order back.

That said... there's an optional feature of the PCIe spec that allows devices to implement automatic lane reversal. So it might work! My Aquantia-based network card seemed to come up in this situation on an M920x without the resistors soldered, though I don't remember what the link width was. But not all devices will work, and it's usually not well-documented whether or not reversal is supported.

Ryanstanley4, 2025-05-07:
If this is the case I think the [README.md](https://github.com/j4cbo/tiny5-m2-riser/blob/main/README.md), should be updated as it reads “_for Lenovo Tiny5 series (M720q/M920q/M920x, etc)”_

I have bought several of these cards for the m720q based on this, it looks like I need to make a new plan.

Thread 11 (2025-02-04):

Orders from EU

CaneTLOTW, 2025-02-04:
Hi, are there any plans to make them available from Europe?

evil2k2, 2025-02-06:
Hey there
I'm currently having 50 pieces produced. But I will assemble them by hand. But it will be a while before I can send out the first ones. I would report here when I'm ready. I come from Germany so EU shipping is no problem.

CaneTLOTW, 2025-02-06:
Das macht den Versand natürlich einfacher ;)

Feel free to add me to the list of interested people with 2 pieces.
Do you already have an idea about pricing?

evil2k2, 2025-02-06:
hehe ja das stimmt natürlich 😉

No not at the moment i'm searching the parts for the project.

lmbacelar, 2025-02-09:
Hi!
I would also be interested in having 2 or 3 of these.
Please let me know when they are available.

devnow, 2025-02-11:
Hi
I would be interested in two riser boards. Shipped to Switzerland or Germany.

Thanks

vgchl, 2025-02-23:
Hi, I'm interested in two boards as well. Shipping to Singapore.

kursatozkan, 2025-03-01:
I am also interested for 4 pcs please. Thanks a lot! Regards,

moe9301, 2025-03-03:
Hi, interested for 2 pcs shipped to Germany :) Nice work

vgchl, 2025-03-03:
@evil2k2 Any estimates on when you'll be ready to ship some out?

evil2k2, 2025-03-03:
I finally got all the parts, only solder paste still missing atm.
But I think I can try to build the first one together these days.

Did no accurate calculation for the price but It should be around 50€.

Loloke, 2025-03-07:
i also interested for 1-2 pcs, shipped to hungary.

j4cbo, 2025-03-10:
@evil2k2 I'd suggest not placing the C5 capacitor - huge thanks to @devnow for noticing the issue with the design in issue #15.

The published version with that capacitor does work (and it's what I've been using in my own server for a few months) but will likely have very poor load transient response, which could lead to system instability.

gastrek, 2025-03-14:
I am interested in 1 PCB as well.

evil2k2, 2025-03-15:
I just finished the first one, tomorrow I'll test it and if everything works I'll do the others.
The ASA filament for the holders will arrive next week and the screws should arrive soon too.

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

joseal, 2025-03-16:
I am also interested in 1 PCB, could you please confirm the price (without the 3d printed parts)?

zididadaday, 2025-03-16:
Hi! Cool that you take the initiative. Can I be added for 2 pieces as well?

AnisseH, 2025-03-18:
Hello
i would be interested for 3 pieces without 3d brackets

otopetrik, 2025-03-20:
Hello,
I am also interested in 1 piece (shipped to Czech Republic).
Thanks!

DavidCarl, 2025-03-21:
Could also be interested in one or two shipped to Danmark :)

Thank you!

zididadaday, 2025-03-21:
> I just finished the first one, tomorrow I'll test it and if everything works I'll do the others. The ASA filament for the holders will arrive next week and the screws should arrive soon too.
>

Finally weekend - how has the testing gone - 💯? @evil2k2

evil2k2, 2025-03-21:
> > I just finished the first one, tomorrow I'll test it and if everything works I'll do the others. The ASA filament for the holders will arrive next week and the screws should arrive soon too.
>
> Finally weekend - how has the testing gone - 💯? [@evil2k2](https://github.com/evil2k2)

All fine works like expected, have 5 done yet.
Screws, esd bags and packaging is also arrived.
But I don't have time rn have a few consoles for repair atm.
3d printed parts are pla+ until I figure out how to print asa right 😅

Would be great if any of you wrote me a mail, but please from first to last.
Write these please also in the mail.
1, 2 and so one
I need the full address, phone number and mail address for shipping outside from Germany.
I use probably UPS for shipping, but I don't have a price for EU shipping.
Outside of EU I must check the shipping possibilities to say a price.

Adresse please like these:
Name:
Adress:
Postcode:
City:
Country:

The price is:
45€ without the 3d printed parts and screws
50€ with these parts and assembled
Payment is only bank transfer (I don't like PayPal)
My mail is: evil.santa.e4s@gmail.com
Will start shipping probably middle next week.

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

PerMejdal, 2025-03-21:
> I just finished the first one, tomorrow I'll test it and if everything works I'll do the others. The ASA filament for the holders will arrive next week and the screws should arrive soon too.

Why print i ASA? It is flamable, and hard to print with.
PETG is not flamable, but still mechanically strong.

evil2k2, 2025-03-21:
I was thinking about ASA because it can withstand high temperatures. But you're right, I should buy PETG instead.
I have just started with 3D printing and have no experience with it yet.

dafula, 2025-03-30:
Hi, I'm interested in 1 piece with 3D printed parts. Shipping to Germany. Is there anything left?

wrobelda, 2025-06-01:
Any update here? Need a riser only, sans 3d parts.

kursatozkan, 2025-06-03:
I was also waiting for these risers without the 3d part. Is it possible to ship two to Bulgaria? Thanks in advance.

gelucrisan, 2025-06-09:
I need two as well, I am located in Romania.
@evil2k2 I was not able to find your email address, can you  please share so I can send you the shipping info?
Thank you

Clarion30, 2025-07-03:
Hallo, hatte schon mal eine email geschrieben, hätte gerne auch eine Karte.

mr4lexndr, 2025-08-13:
Hi All,

I have made a **batch of boards**.
📟  They are **available [here](https://www.tindie.com/products/letbco/pcie-riser-2x-nvme-x4-for-lenovo-tiny-m920m720/)**
📦 I ship them from the UK and the EU.

🔩 As an add-on, you can also obtain all the necessary **fasteners and brackets**.

wrobelda, 2025-10-01:
@Piorek99 did you solder the SMD elements on the motherboard as instructed?

mr4lexndr, 2025-10-01:
> [@Piorek99](https://github.com/Piorek99) did you solder the SMD elements on the motherboard as instructed?

@Piorek99, this would be the most likely cause of the problem. J1 uses PCIe lanes from PCH, which should work regardless of bifurcation. J2 will not work, and J3 might work, but I haven't tested it.

Bifurcation is done by soldering two SMD resistors at the bottom of the motherboard, as explained in this repo.

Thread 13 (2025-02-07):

Booting from SSD connected via riser

derpicknicker1, 2025-02-07:
I tried to boot from a ssd connected via the riser. But I can not see the ssd in the boot menu. Tried both slots of the riser. If I use the onboard slots, it works like expected. Is this a known 'issue' or am I doing something wrong?

dionorgua, 2025-02-07:
System BIOS is pretty limited. Even if you plug SSD to wifi slot (via adapter) system will not detect it as bootable device.
At the same time system will boot  from it if there is no more options available

evil2k2, 2025-02-07:
You need to install your operating system to this drive.
Also be sure you don't have other systems installed also remove all drives from boot order in bios.
This works also with ssd connected to WiFi Slot.

j4cbo, 2025-02-09:
Yep, as @dionorgua said, this is expected. SSDs connected to anything besides the on-motherboard M.2 slots will not appear in the BIOS or the boot menu, so you'll need to use one of them (or SATA) for your boot drive. My understanding is that if there are no other bootable devices, the BIOS will be able to boot from drives on the riser even though they don't appear in the menu, but I haven't tried it myself.

dionorgua, 2025-02-10:
My m920x is booting from 2242 SSD connected to 'wifi' slot. This is my 'production' setup.

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

It works but you need to make sure you don't have anything bootable on 'supported' drives (two standard m.2 SSDs or SATA caddy)

ilium007, 2025-07-17:
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

Nice setup. Do you have a link to the M.2-E to nVME adaptor?

Closed 2025-02-09.

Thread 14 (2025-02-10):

Do you think a riser for 12x or 8x nvme archivable ?

ersandemirayak, 2025-02-10:
3x or 2x  asm1184 to extend the number of nvme to 12/8, for a SSD NAS card?

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

CaneTLOTW, 2025-02-17:
Some KI based remarks ;)

Below is a high-level explanation of what’s going on with the ASMedia ASM1184 switch (and similar chips in the ASMedia product line) and why you’ll often see advice pointing toward a “real” PCIe switch (like Broadcom/PLX) when trying to fan out to many NVMe devices.

---

## 1. What is the ASM1184?

- **ASM1184** is a relatively small PCIe packet switch that typically provides 1 upstream PCIe lane and up to 4 downstream ports (often each is a single-lane link as well).
- It is usually marketed for adding multiple USB3 controllers, small M.2 (WiFi/SSD) slots, or other low-bandwidth devices behind a single x1 or x2 link.
- You’ll sometimes see it on “quad M.2 adapters” that each slot is forced to use PCIe x1, or on riser boards to attach multiple small devices to a single host port.

Because each downstream port in many ASM1184-based designs is only **PCIe x1**, each NVMe SSD—if attached directly—would be limited to x1 bandwidth. That can be enough for embedded or low-end uses (still hundreds of MB/s per SSD), but it does *not* tap the full performance typical NVMe drives can deliver at x4.

---

## 2. Can I chain or combine multiple ASM1184 chips to get 8 or 12 NVMe drives?

In principle, yes:
- You could place two or three ASM1184 chips on a single board, each connected to the upstream slot (or chained from each other).
- This would give you 2× or 3× “4-port groups,” so 8 or 12 potential downstream ports in total.

However, there are significant design and performance caveats:

1. **Upstream Lane Width** – The ASM1184 generally expects a single-lane or dual-lane upstream (depending on variant). Even if you feed 2 or 3 ASM1184 chips from (for example) a PCIe x4 slot, you still have to subdivide that x4 into multiple x1 or x2 links per chip. As soon as you start slicing up a single x4 link into multiple x1 “branches,” each group of 4 M.2 slots behind an ASM1184 is contending for limited upstream bandwidth. This can severely limit the total performance if all drives are active.

2. **Chaining Complexity** – You can chain small PCIe switches (one ASM1184 attached upstream, with others downstream), but the link negotiations and bridging can get tricky. It can become finicky or unstable unless carefully designed—and you still share the same limited total bandwidth.

3. **Firmware/Compatibility** – Some motherboards or BIOS/UEFI firmwares are pickier than others about enumerating multiple chained PCIe bridges. You may encounter boards that simply won’t show all the drives or that get stuck at boot, requiring advanced firmware patches or luck.

Because of these constraints, you do not commonly see “3× ASM1184 for 12 M.2 NVMe” or “2× ASM1184 for 8 M.2 NVMe” as a mainstream product. It *can* be done, but:

- You often end up saturating a single-lane (or x2) upstream link, making the performance for each drive quite low.
- The card design becomes more complex; at that point, it’s usually more cost- and performance-effective to switch to a bigger, full-fledged PCIe switch.

---

## 3. Using a “Real” PCIe Switch (PLX/Broadcom, Microchip, or ASMedia ASM28xx)

When you see high-end “8-port” or “16-port” NVMe carrier boards, they typically use a larger PCIe switch, such as:

- **Broadcom (PLX) PEX series** (e.g., PEX 8718, 8732, 8747, etc.)
- **Microchip Switchtec** series
- **ASMedia ASM2812 / ASM2824** (supporting more lanes/ports and higher bandwidth)

These chips:
- Accept a wider upstream interface (e.g., PCIe x8 or x16).
- Provide multiple *x4 or x2* downstream ports, so you can run each NVMe at near its native PCIe 3.0 or 4.0 speeds.
- Have more mature firmware for enumerating a large number of endpoints behind one switch.

For an **SSD NAS card** (implying you truly want to push multi-gigabyte per second read/write performance across multiple M.2 drives), you really want an actual multi-lane upstream and a proper switch chip that can feed each drive with enough bandwidth. That’s the difference between a “fun experiment with lots of x1 drives behind multiple cheap switches” and a stable, high-performance storage solution.

---

## 4. Conclusion

- **3× or 2× ASM1184** to get 12 or 8 M.2 slots is *technically* possible, but generally not recommended for true NVMe performance because you will be severely bottlenecked by the upstream lane(s), plus the design/compatibility headaches of chaining multiple small switches.
- If your use-case only needs each drive at ~500–900 MB/s (PCIe 3.0 x1 speeds) for lower-end “NAS” throughput, then you could explore it. Just be aware it’s outside the typical reference design, and you may run into motherboard/BIOS quirks.
- For a robust multi-SSD NAS solution at full NVMe speeds, look at a larger (and unfortunately more expensive) PCIe switch solution—e.g., a **PLX/Broadcom** or **ASM28xx**-based board—which can properly fan out x8 or x16 upstream to multiple x4 M.2 ports. That’s how commercial 8+ port NVMe HBAs or storage boards do it.

In short, “yes, you *could* do 2× or 3× ASM1184,” but “no, it usually doesn’t give you the kind of performance or stability you expect from a proper 8–12 port NVMe card.” If you need a serious SSD NAS card, a bigger switch chip is the way to go.

j4cbo, 2025-02-17:
I'd be worried about power supply and thermal limits... plus, fitting PCIe switches on the back of the riser with connectors on the front would likely require switching to an expensive HDI PCB process. In short, not on my to-do list :)

evil2k2, 2025-03-16:
There are two cards available with integrated PCIe switching Chip.

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

https://a.aliexpress.com/_Ev5BUx2
4x NVMe

Or this beast
8x NVMe with X16 connector (works down to X4)

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

Both are fitting more or less in an Lenovo Tiny 5 (m720, m910x, m920)

Closed 2025-03-13.

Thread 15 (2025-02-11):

buck converter v2 remarks

devnow, 2025-02-11:
Thanks for releasing the designs. Remark on the buck converter feedback loop [3], the datasheet is unusually sparse on information.
The data sheet recommends (Table 8-2. Recommended Component Values [1]) a R6=20k, R5=90k (or 91k for E24 values) for 3.3V and a feed forward capacitor C_FF=C5 between 0-100pF. The reference boars use 22pF [2]. Output Voltage Setpoint V_OUT = 0.6 * (1+ R_upper/R_lower) [2]
I have no experience in NV drives current profiles. Judging from your v2 design notes it's not your first pci-e design rodeo, glad to learn for further insights.

[1] [TPS51386 data sheet](https://www.ti.com/lit/ds/symlink/tps51386.pdf)
[2] [User's Guide TPS51386 Step-Down Converter Evaluation Module](https://www.ti.com/lit/ug/sluucn0b/sluucn0b.pdf)
[3] [Design considerations for a resistive feedback divider in a DC/DC converter](https://www.ti.com/lit/an/slyt469/slyt469.pdf)

j4cbo, 2025-03-10:
Good catch! The feedback resistors were chosen to give an acceptable output voltage while staying within the E12 series, but the capacitor is just a copy-paste error. 😬 Props to TI for building a control loop that works with such excessive feedforward capacitance.

It's interesting that the EVM includes a capacitor at all there... the datasheet notes that the regulator "does not require external compensation" and the reference schematic on page 1 doesn't include one, so I'm going to suggest just removing C5 instead. I'll send an email to everyone who's purchased a V2 board and update the schematics in git.

Fironet, 2025-03-15:
> so I'm going to suggest just removing C5 instead

Just to confirm, you're suggesting users desolder the component circled here?

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

crimeofheart, 2025-06-08:
> Good catch! The feedback resistors were chosen to give an acceptable output voltage while staying within the E12 series, but the capacitor is just a copy-paste error. 😬 Props to TI for building a control loop that works with such excessive feedforward capacitance.
>
> It's interesting that the EVM includes a capacitor at all there... the datasheet notes that the regulator "does not require external compensation" and the reference schematic on page 1 doesn't include one, so I'm going to suggest just removing C5 instead. I'll send an email to everyone who's purchased a V2 board and update the schematics in git.

I guess v1 owners are safe?

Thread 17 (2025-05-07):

Using a cheaper inductor

kqkq, 2025-05-07:
The design uses a XAL7070-182MEC 1.8uH inductor, which is really expensive!

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

Can we change to a generic 1.5uH inductor? It is 1/20 the price of the current design.

j4cbo, 2025-05-21:
The inductor was cheap when I chose it 😅 there's nothing special about it, a generic 1.5 or 2.2uH inductor ought to work fine too.

Closed 2025-05-22.

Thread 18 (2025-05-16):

配置电阻是2个还是3个？

xianxixi, 2025-05-16:
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
根据这张图，配置电阻不应该有3个吗？cfg2,cfg5,cfg6

j4cbo, 2025-05-16:
CFG5 (R888) is already set at the factory, so only the resistors for CFG2 (R885) and CFG6 (R889) need to be added:
CFG5（R888）已在工厂设置，因此只需添加 CFG2（R885）和 CFG6（R889）的电阻：

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

kqkq, 2025-05-21:
Don't ever try to replicate this design in China. The inductor and M.2 connectors are insanely expensive. You may want a redesign and use parts easily available in China. 不要尝试在国内复刻这个设计，他选的电感、电源芯片、M.2连接器都贵的离谱。最好是重新设计并选用国内容易买到的零件。

j4cbo, 2025-05-21:
Those vertical M.2 connectors are hard to find. If there's a cheaper option, I'd like to hear about it :) The inductor can be substituted too.

kqkq, 2025-05-21:
> Those vertical M.2 connectors are hard to find. If there's a cheaper option, I'd like to hear about it :) The inductor can be substituted too.

regarding the M.2 connector, could you consider to change to:

Brand: LOTES
Model: APCI0110-P001A
JLC number: C841669

this only cost 1/10 of the current connector.

j4cbo, 2025-05-21:
That connector puts the M.2 card parallel to the riser, but it needs to be sticking out at a 90 degree angle :(

kqkq, 2025-05-22:
> That connector puts the M.2 card parallel to the riser, but it needs to be sticking out at a 90 degree angle :(

APCI011-P001-A is the correct model, but the LCSC number is incorrect... My bad...

I know it needs to be vertical. However, this model is not available at LCSC. Can you check AliExpress or other websites?

Thank you.

j4cbo, 2025-06-01:
Do you know where to find a datasheet for any of these? It looks like many are available from various sellers on Aliexpress, but I can't find a dimensioned drawing anywhere. They might be compatible with the same layout but it'd be good to be able to check...

kqkq, 2025-06-03:
> Do you know where to find a datasheet for any of these? It looks like many are available from various sellers on Aliexpress, but I can't find a dimensioned drawing anywhere. They might be compatible with the same layout but it'd be good to be able to check...

I don't have the datasheet. I did purchase some to try, but the footprint is not compatible.

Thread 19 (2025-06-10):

An opportunity to fix IOMMU grouping here for PCI devices

wrobelda, 2025-06-10:
Hi,

I was investigating the IOMMU group separation for my x710-DA2 multi-function NIC and it hit me that this project could actually fix an underlying issue with these Tiny devices, i.e. that all the NICs on these cards end up in the same IOMMU group:

```
01:00.0 Ethernet controller: Intel Corporation Ethernet Controller X710 for 10GbE SFP+ (rev 02)
	Subsystem: Intel Corporation Ethernet 10G 2P X710 Adapter
	Flags: bus master, fast devsel, latency 0, IRQ 16, IOMMU group 2
(...)
01:00.1 Ethernet controller: Intel Corporation Ethernet Controller X710 for 10GbE SFP+ (rev 02)
	Subsystem: Intel Corporation Ethernet Converged Network Adapter X710
	Flags: bus master, fast devsel, latency 0, IRQ 16, IOMMU group 2
```

This is down to the fact that the CPUs used by these desktops do not support Access Control Services (ACS), which would otherwise allow separating these into different groups. Sure, there's a known hack/workaround (`pcie_acs_override`), but it's risky and doesn't always work — and it indeed does not work with these particular Lenovo desktops (at least m920x and p350 that I owned).

That having said, the PCH's PCI bridge actually *does* support ACS, see:

```
root@pve2:~# lspci -vvv -s 00:1b.0
00:1b.0 PCI bridge: Intel Corporation Cannon Lake PCH PCI Express Root Port #21 (rev f0) (prog-if 00 [Normal decode])
	Subsystem: Lenovo Cannon Lake PCH PCI Express Root Port
(...)
	Capabilities: [140 v1] Access Control Services
		ACSCap:	SrcValid+ TransBlk+ ReqRedir+ CmpltRedir+ UpstreamFwd- EgressCtrl- DirectTrans-
		ACSCtl:	SrcValid+ TransBlk- ReqRedir+ CmpltRedir+ UpstreamFwd- EgressCtrl- DirectTrans-
```

Which means that if the x4 PCI slot was actually wired to the PCH instead of CPU-bound PCI lane, the NICs would be placed in separate IOMMU groups. Having them in separate groups have obvious advantage, as it allows to pass them through to separate VMs independently and in a memory-safe manner.

Which makes me wonder if there's a way you could design another version of this riser, this time having both m2 slots wired to PCI lanes and the PCI slot to PCH lane?  To be honest, I think it actually makes more sense anyway to have both m2 drives wired the same way?

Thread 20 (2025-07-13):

How are you fitting the SATA boot SSD in the case?

ilium007, 2025-07-13:
With the additional nvme drives, PCIe card (assuming 10GB or 2.5GB NIC), how are you fitting the boot SSD via the SATA flex cable? Do you have any more pics on how you have it all fitting?

I have a Lenovo P330 Tiny I am considering doing this mod on - awesome project! If this works it will solve so many home lab problems for me!

My P330 has a large black heatsink plate under the PCIe card / SSD position:

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

<!-- Failed to upload "image.png" -->

ilium007, 2025-07-17:
I have purchased one of these as they are quite small - just need a 2230 SATA SSD.

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

j4cbo, 2025-07-17:
Interesting, my m920x doesn't have that heatspreader. Maybe it's specific to the P330 Tiny?

I used a SanDisk "Half Slim" SSD and designed an extra 3d-printed piece that goes underneath the m2-mount component with some arms that come off to hold the SSD. You could probably do something similar with your 2230 adapter. Here's how it fits together:

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

ctcDNightmare, 2025-09-09:
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

Interesting, my m920x also has that heatsink installed but I couldn't find it in the maintenance docs from Lenovo for either the p330 or the 920x 🤷

Could you share the .stl of that additional adapter by any chance? Looked in the repo, but so far didn't see them or I'm blind

Trying to squeeze everything planned in the m920x is a challenge, your bracket sure will help.
(2x m.2, 1x sata, 1x sas 4e hba, wifi-slot > 2.5gb nic)

zollak, 2025-09-09:
Hi guys! It is an awesome project! Thanks for sharing this! Would you mind to share some info about the available speeds? I know it depends on many things, but knowing the nvme types and the measured bandwidth would be super welcome!

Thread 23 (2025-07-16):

How do I know L1 is oriented correctly in JLPCB PCBA editor

ilium007, 2025-07-16:
The L1 footprint image in the PCBA tool on JLPCB does not have any clear way to know orientation of the pads underneath.

Should it be like this (as per CPL file):

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

This is it in 3D view when placed as per CPL file - I assume this is the correct orientation:

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

Or this (rotated 90º):

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

Datasheet for the inductor has the label sideways to fit the pads on this PCB:

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

j4cbo, 2025-07-16:
As it is in the CPL file is correct - if you shift it off the board and then use the 3D view to peek underneath, you should be able to more clearly see the orientation of the pads.

I don't think the "L1" label in the JLC rendering corresponds to the orientation of the text on the part.

ilium007, 2025-07-17:
Thanks - awesome project by the way. I submitted a minor pull request to fix the BOM that I submitted to JLPCB. When you get a chance can you have a look at my JLPCB settings on the other issue I raised? I have 5 boards I am going to submit for build after the M.2 headers are sourced.

Closed 2025-07-17.

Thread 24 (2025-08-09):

The computer burned out with the board connected.

klaudiawlodarskaa-ui, 2025-08-09:
Hi, I ordered three boards from JLCPCB exactly according to the instructions. Nothing was modified. The first board worked for a while, but when I reconnected it, the computer burned out. There was smoke and a foul smell coming from the computer's ventilation grille near the power plug. The computer already had two M.2 drives connected. The second computer burned out the first time with the same configuration, the only difference being that the first time, the case was not closed while the computer was running. I don't know if this has any effect, but the computer has a case closure sensor. The third computer had a other board connected, without drives, and it also burned out the first time. Do you have any suggestions as to what might have happened? All the computers were m920x with different specifications.

j4cbo, 2025-08-12:
Yikes, that definitely shouldn't happen!

The oscillator provides the M.2 `SUSCLK` signal, which is supposed to be present in suspend states where I wasn't sure if 3V3 would be available. Most NVMe devices don't require it but some do. It might be safest to just remove the oscillator entirely?

Also, is there any chance the riser was connected or removed while the system was plugged in (even if powered down)?

mr4lexndr, 2025-08-12:
In my case (I burned two PCs), the riser was connected before the power was plugged in. However, I had boot enabled on power loss, so it turned on immediately after plugging in the supply. In one of them, it worked for the first time and then burned after the second plug-in.

The strange part is that 3V3_S5 is capable of 5A and the oscillator wouldn't draw more than 1.5mA. Is there any case that could directly cause this failure?

mr4lexndr, 2025-08-12:
I did further testing.

After replacing the mentioned MOSFET, it was running fine without PCIE bifurcation (two cfg resistors not present), riser in the slot. With resistors in place and the riser in, it burned red straight away.

The next step was to replace the MOSFET again and test without the riser. All ok.

Then I removed the oscillator from the riser (the only thing connected to the 3V3_S5 line of the MOSFET), put it in place, and the MOSFET glowed red again with a lot of smoke.

Currently, I am out of ideas, as I cannot find any other relation of 3V3_S5 MOSFET to the riser or PCIe.

j4cbo, 2025-08-12:
I'm baffled too. I would expect that MOSFET to win a fight with just about anything on the riser board, and I really don't understand how disabling or enabling bifurcation would affect the outcome.

The FET glowing and smoking makes me suspect a hard short to ground. Maybe there's intermittent contact and removing/reinserting the riser changes the alignment enough to make a difference? It's a long shot but it's all I've got.

crimeofheart, 2025-08-12:
@mr4lexndr Can you upload a photo showing how exactly you did it? I already replaced mosfets twice and want this drama to end already :)

Thanks in advance!

mr4lexndr, 2025-08-12:
The first photo shows an incorrect, although possible, way to insert the riser. Pay close attention to the alignment of pads with pins in the socket. The second photo is correct.

The next two show which pads I cut out with a scalpel for testing. This is unnecessary now (if you want to keep full compatibility), once I realised it should be correctly inserted. In my case, the riser should be pushed towards the power button.

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

klaudiawlodarskaa-ui, 2025-08-17:
Thank you so much!, especially to mr4lexndr, replacing the transistor and checking the connection in the riser helped. I am closing this issue!

Closed 2025-08-17.

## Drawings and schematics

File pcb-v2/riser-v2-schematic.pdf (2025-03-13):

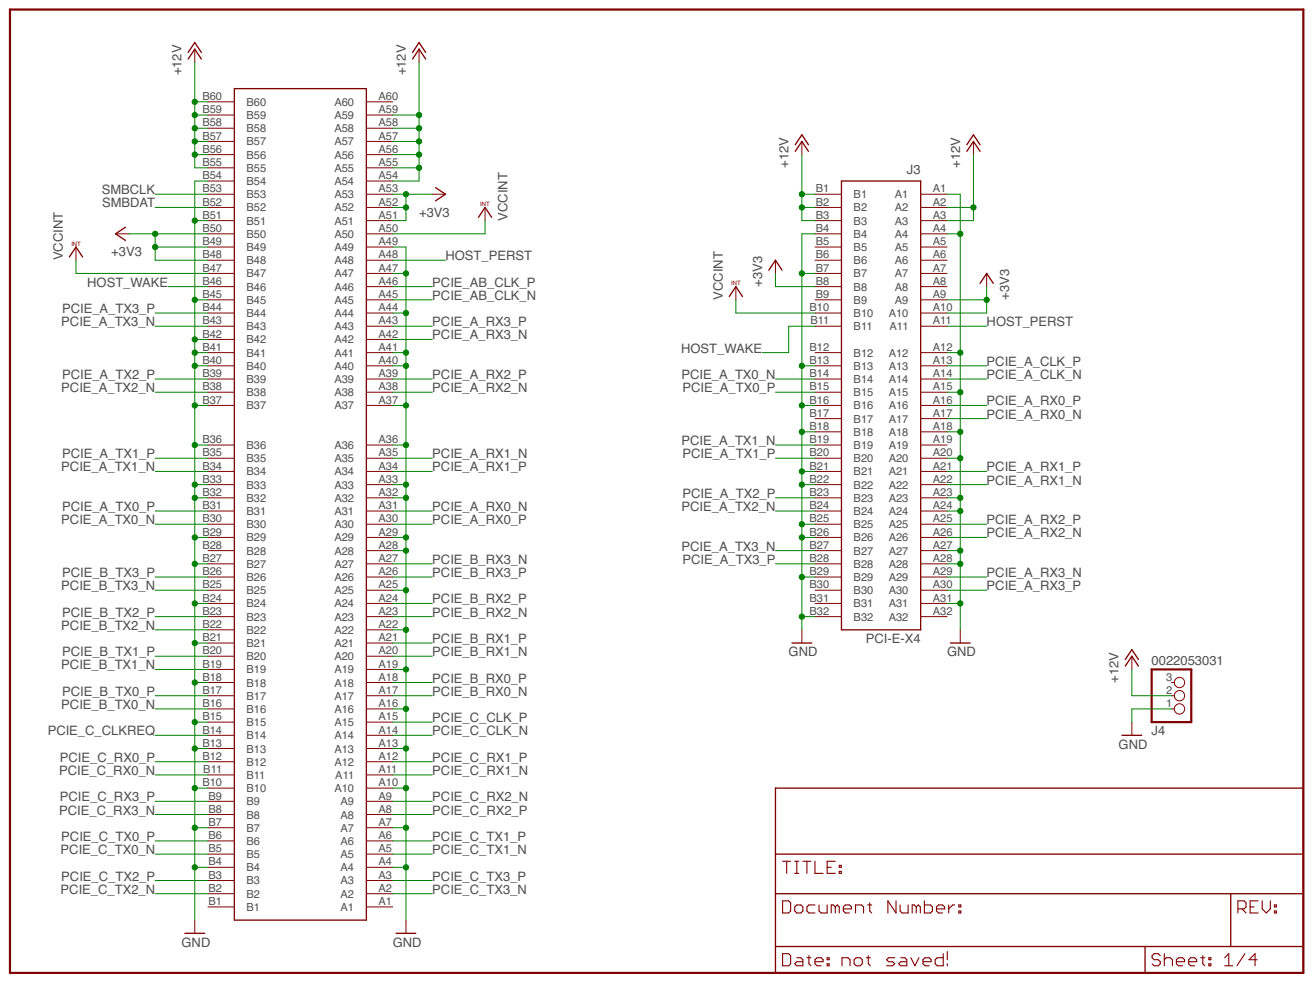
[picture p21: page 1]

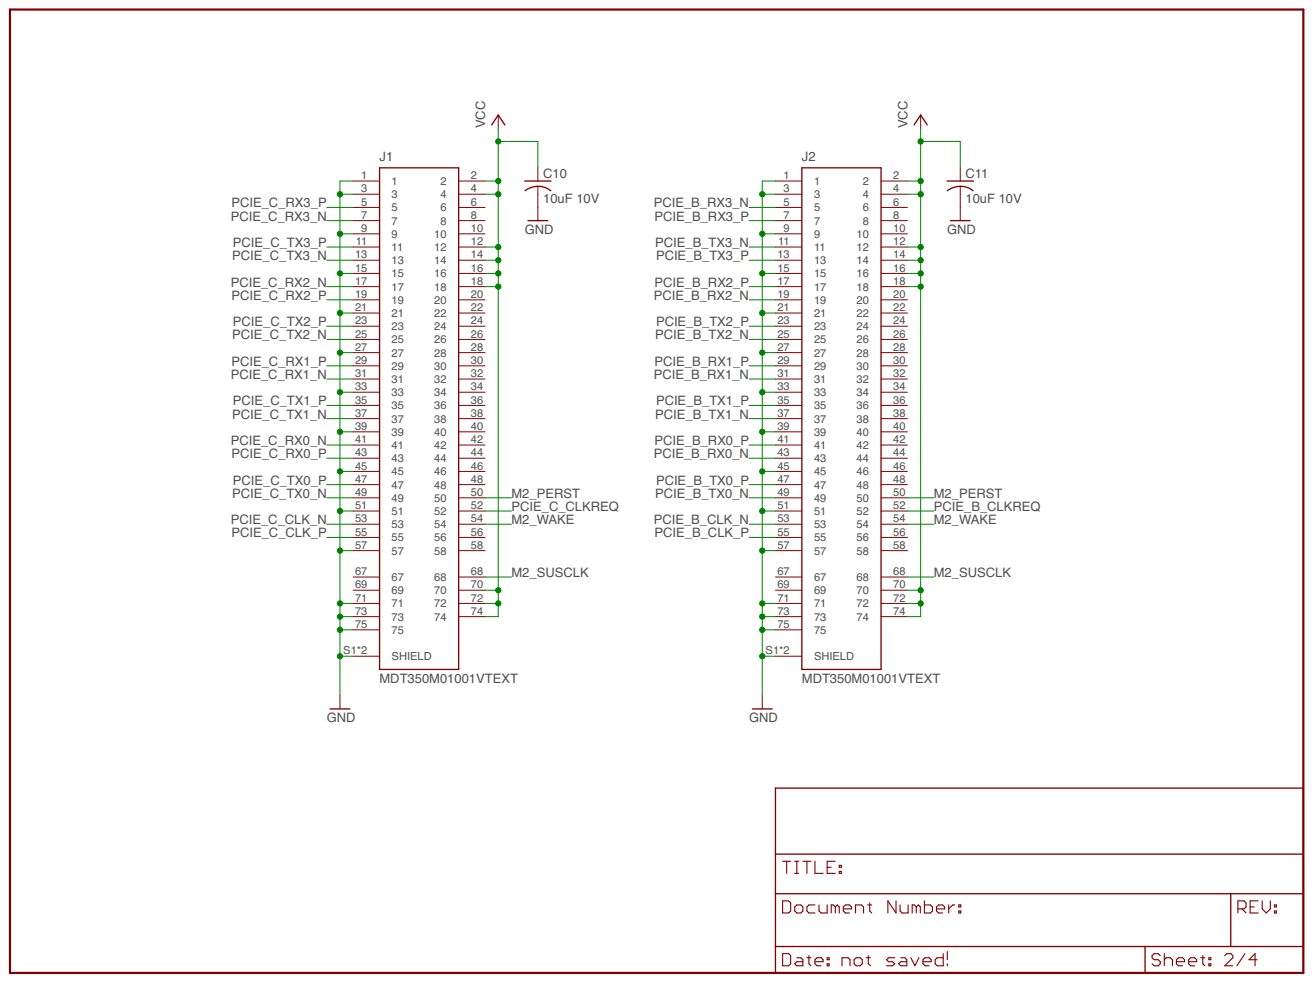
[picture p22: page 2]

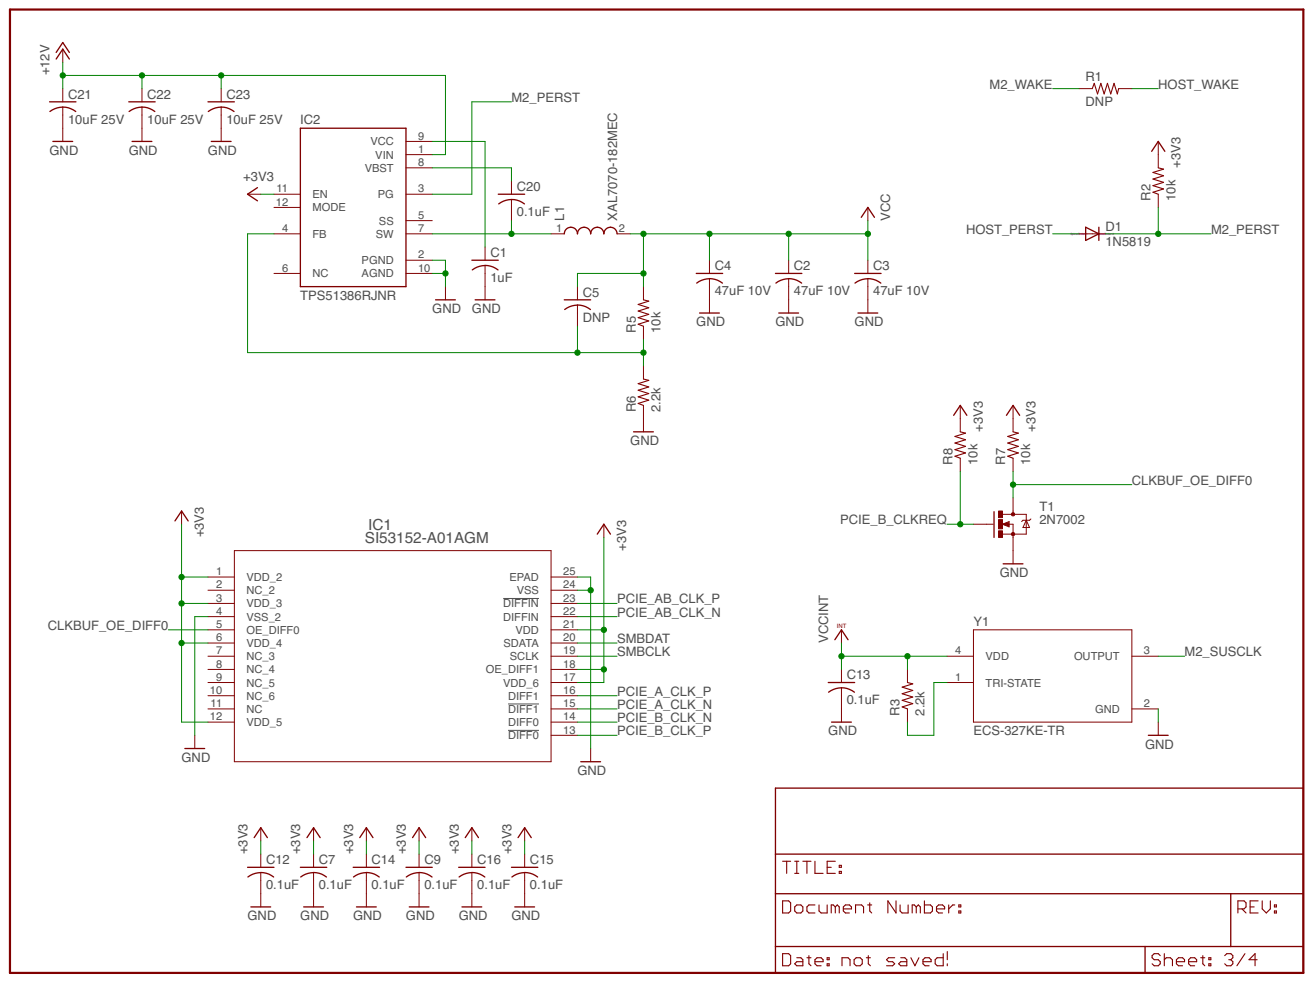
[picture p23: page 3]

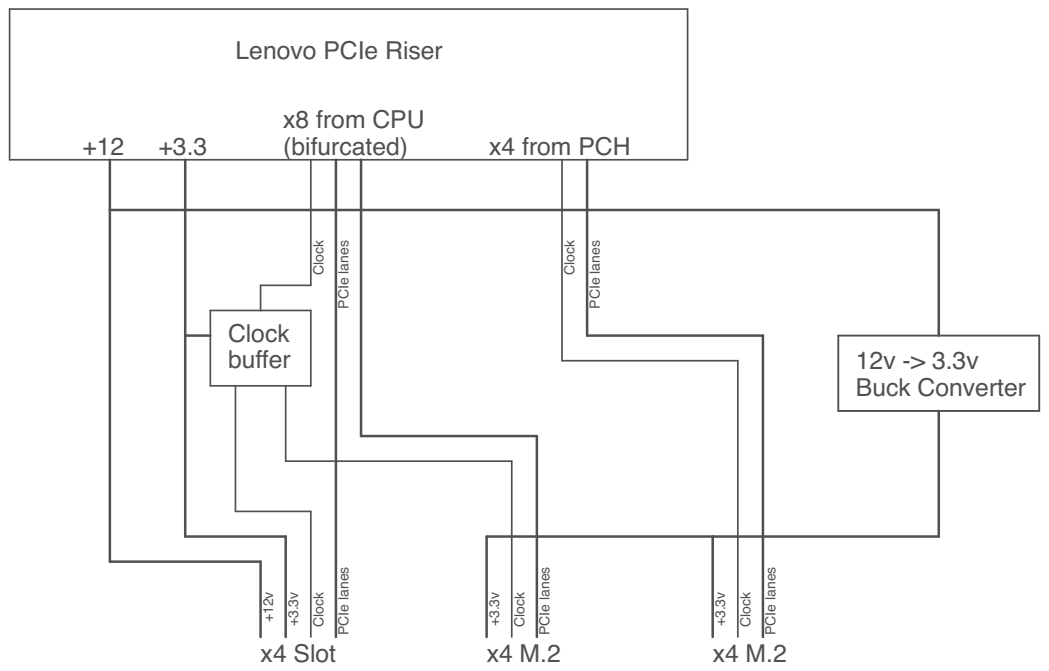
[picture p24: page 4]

Lenovo PCIe Riser x8 from CPU

PCIe lanes

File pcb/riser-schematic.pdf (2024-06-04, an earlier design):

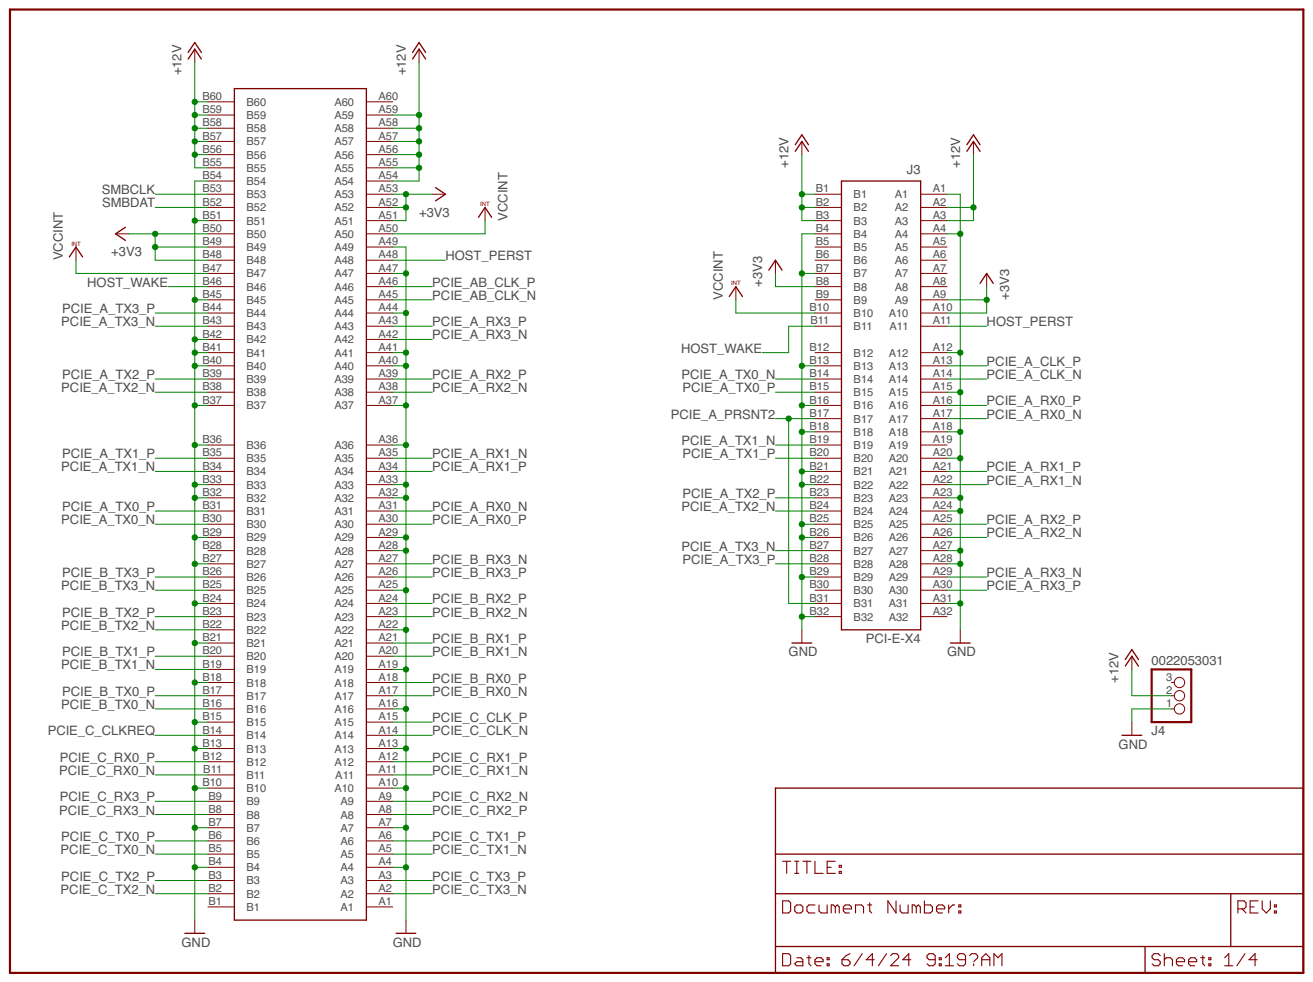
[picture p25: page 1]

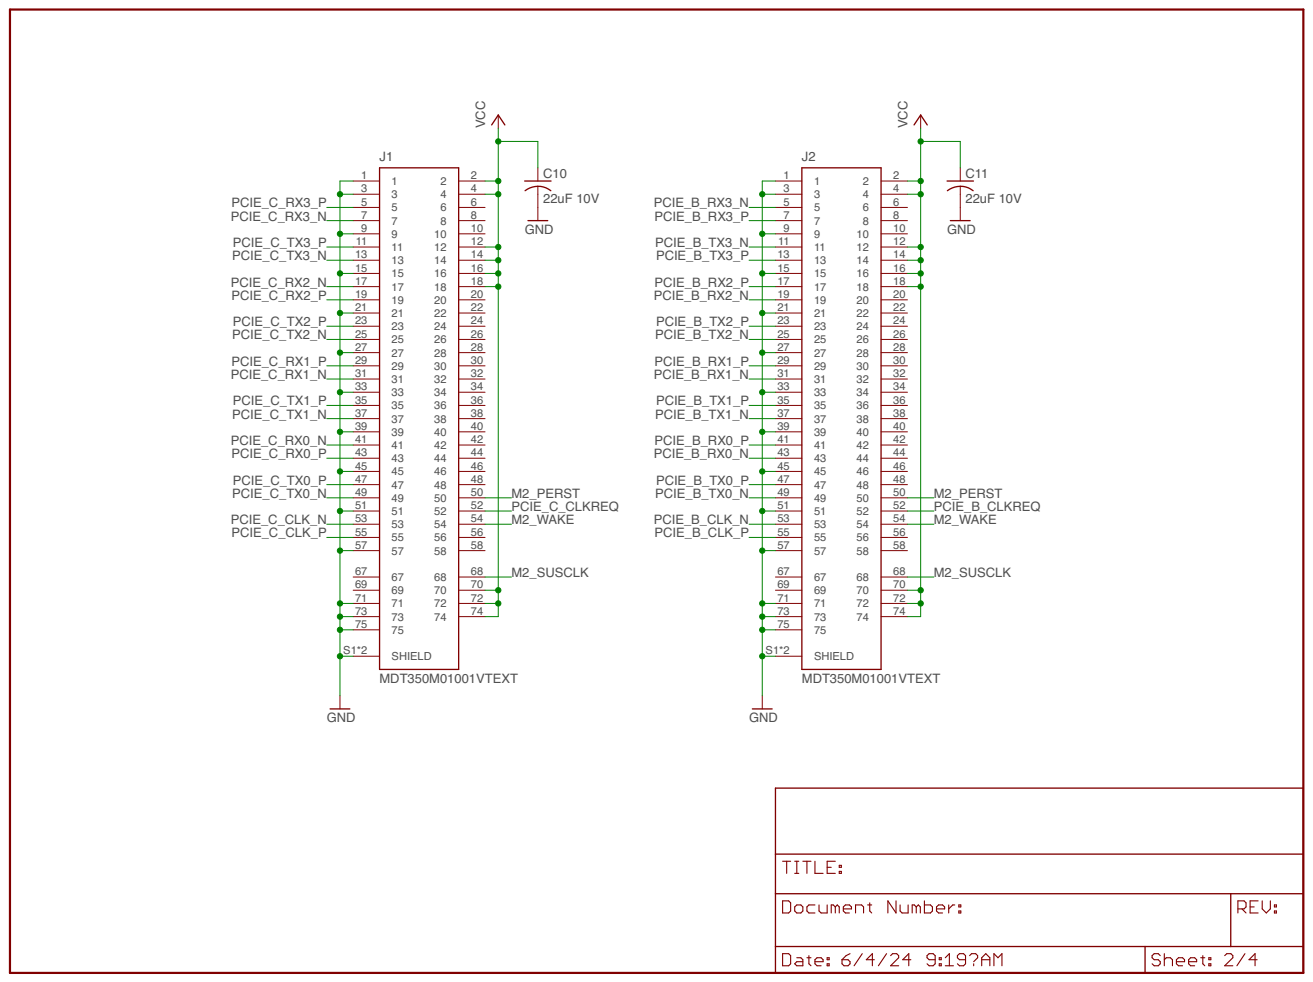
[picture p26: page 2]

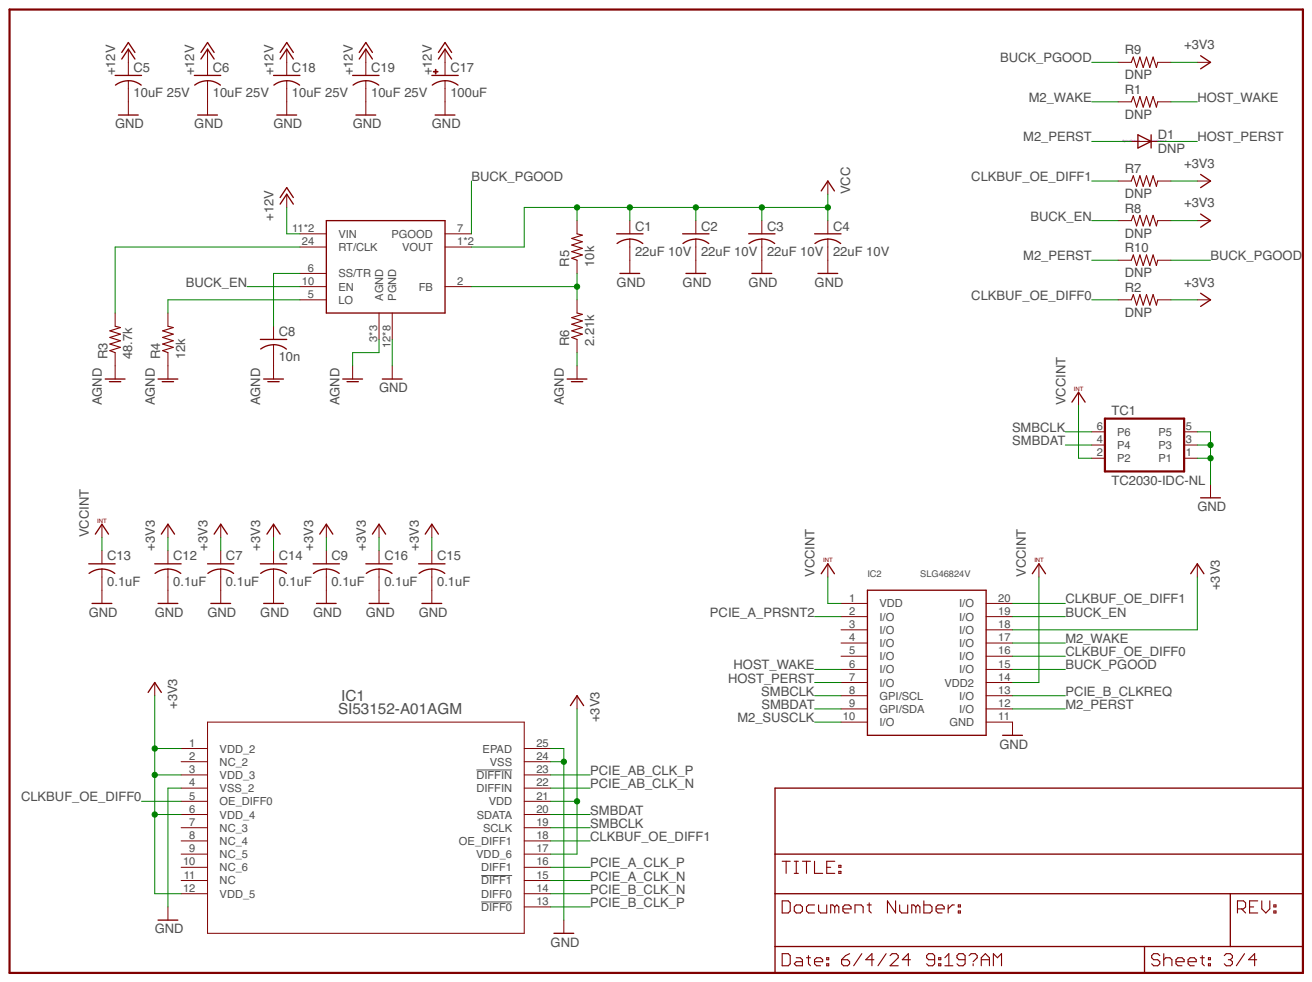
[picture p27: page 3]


Lenovo PCIe Riser x8 from CPU

PCIe lanes

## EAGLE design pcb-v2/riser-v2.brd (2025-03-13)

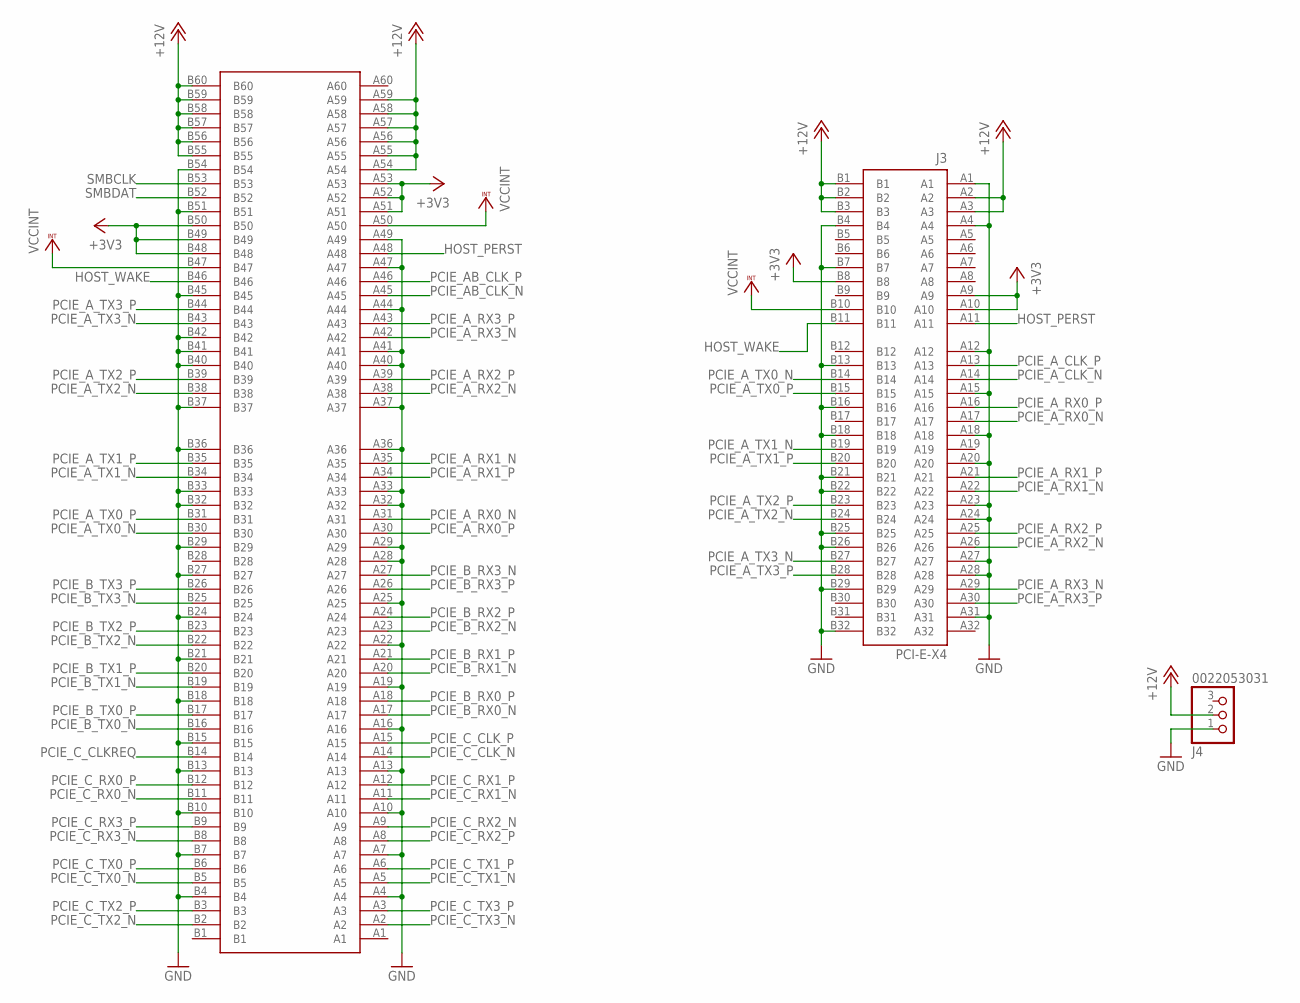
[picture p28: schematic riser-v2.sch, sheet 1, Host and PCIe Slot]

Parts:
J3: PCI-E-X4
J4: 0022053031; 1X03
JP1: ADDR0262; ADDR0262-EDGE

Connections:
+3V3: J3.A9, J3.A10, J3.B8, JP1.A51, JP1.A52, JP1.A53, JP1.B48, JP1.B49, JP1.B50; also elsewhere on the board
+12V: J3.A2, J3.A3, J3.B1, J3.B2, J3.B3, J4.2, JP1.A54, JP1.A55, JP1.A56, JP1.A57, JP1.A58, JP1.A59, JP1.B55, JP1.B56, JP1.B57, JP1.B58, JP1.B59, JP1.B60; also elsewhere on the board
GND: J3.A1, J3.A4, J3.A12, J3.A15, J3.A18, J3.A20, J3.A23, J3.A24, J3.A27, J3.A28, J3.A31, J3.B4, J3.B7, J3.B13, J3.B16, J3.B18, J3.B21, J3.B22, J3.B25, J3.B26, J3.B29, J3.B32, J4.1, JP1.A4, JP1.A7, JP1.A10, JP1.A13, JP1.A16, JP1.A19, JP1.A22, JP1.A25, JP1.A28, JP1.A29, JP1.A32, JP1.A33, JP1.A36, JP1.A37, JP1.A40, JP1.A41, JP1.A44, JP1.A47, JP1.A49, JP1.B4, JP1.B7, JP1.B10, JP1.B13, JP1.B15, JP1.B18, JP1.B21, JP1.B24, JP1.B27, JP1.B29, JP1.B32, JP1.B33, JP1.B36, JP1.B37, JP1.B40, JP1.B41, JP1.B42, JP1.B45, JP1.B51, JP1.B54; also elsewhere on the board
HOST_PERST: J3.A11, JP1.A48; also elsewhere on the board
HOST_WAKE: J3.B11, JP1.B46; also elsewhere on the board
PCIE_AB_CLK_N: JP1.A45; also elsewhere on the board
PCIE_AB_CLK_P: JP1.A46; also elsewhere on the board
PCIE_A_CLK_N: J3.A14; also elsewhere on the board
PCIE_A_CLK_P: J3.A13; also elsewhere on the board
PCIE_A_RX0_N: J3.A17, JP1.A31
PCIE_A_RX0_P: J3.A16, JP1.A30
PCIE_A_RX1_N: J3.A22, JP1.A35
PCIE_A_RX1_P: J3.A21, JP1.A34
PCIE_A_RX2_N: J3.A26, JP1.A38
PCIE_A_RX2_P: J3.A25, JP1.A39
PCIE_A_RX3_N: J3.A29, JP1.A42
PCIE_A_RX3_P: J3.A30, JP1.A43
PCIE_A_TX0_N: J3.B14, JP1.B30
PCIE_A_TX0_P: J3.B15, JP1.B31
PCIE_A_TX1_N: J3.B19, JP1.B34
PCIE_A_TX1_P: J3.B20, JP1.B35
PCIE_A_TX2_N: J3.B24, JP1.B38
PCIE_A_TX2_P: J3.B23, JP1.B39
PCIE_A_TX3_N: J3.B27, JP1.B43
PCIE_A_TX3_P: J3.B28, JP1.B44
PCIE_B_RX0_N: JP1.A17; also elsewhere on the board
PCIE_B_RX0_P: JP1.A18; also elsewhere on the board
PCIE_B_RX1_N: JP1.A20; also elsewhere on the board
PCIE_B_RX1_P: JP1.A21; also elsewhere on the board
PCIE_B_RX2_N: JP1.A23; also elsewhere on the board
PCIE_B_RX2_P: JP1.A24; also elsewhere on the board
PCIE_B_RX3_N: JP1.A27; also elsewhere on the board
PCIE_B_RX3_P: JP1.A26; also elsewhere on the board
PCIE_B_TX0_N: JP1.B16; also elsewhere on the board
PCIE_B_TX0_P: JP1.B17; also elsewhere on the board
PCIE_B_TX1_N: JP1.B19; also elsewhere on the board
PCIE_B_TX1_P: JP1.B20; also elsewhere on the board
PCIE_B_TX2_N: JP1.B22; also elsewhere on the board
PCIE_B_TX2_P: JP1.B23; also elsewhere on the board
PCIE_B_TX3_N: JP1.B25; also elsewhere on the board
PCIE_B_TX3_P: JP1.B26; also elsewhere on the board
PCIE_C_CLKREQ: JP1.B14; also elsewhere on the board
PCIE_C_CLK_N: JP1.A14; also elsewhere on the board
PCIE_C_CLK_P: JP1.A15; also elsewhere on the board
PCIE_C_RX0_N: JP1.B11; also elsewhere on the board
PCIE_C_RX0_P: JP1.B12; also elsewhere on the board
PCIE_C_RX1_N: JP1.A11; also elsewhere on the board
PCIE_C_RX1_P: JP1.A12; also elsewhere on the board
PCIE_C_RX2_N: JP1.A9; also elsewhere on the board
PCIE_C_RX2_P: JP1.A8; also elsewhere on the board
PCIE_C_RX3_N: JP1.B8; also elsewhere on the board
PCIE_C_RX3_P: JP1.B9; also elsewhere on the board
PCIE_C_TX0_N: JP1.B5; also elsewhere on the board
PCIE_C_TX0_P: JP1.B6; also elsewhere on the board
PCIE_C_TX1_N: JP1.A5; also elsewhere on the board
PCIE_C_TX1_P: JP1.A6; also elsewhere on the board
PCIE_C_TX2_N: JP1.B2; also elsewhere on the board
PCIE_C_TX2_P: JP1.B3; also elsewhere on the board
PCIE_C_TX3_N: JP1.A2; also elsewhere on the board
PCIE_C_TX3_P: JP1.A3; also elsewhere on the board
SMBCLK: JP1.B53; also elsewhere on the board
SMBDAT: JP1.B52; also elsewhere on the board
VCCINT: J3.B10, JP1.A50, JP1.B47; also elsewhere on the board

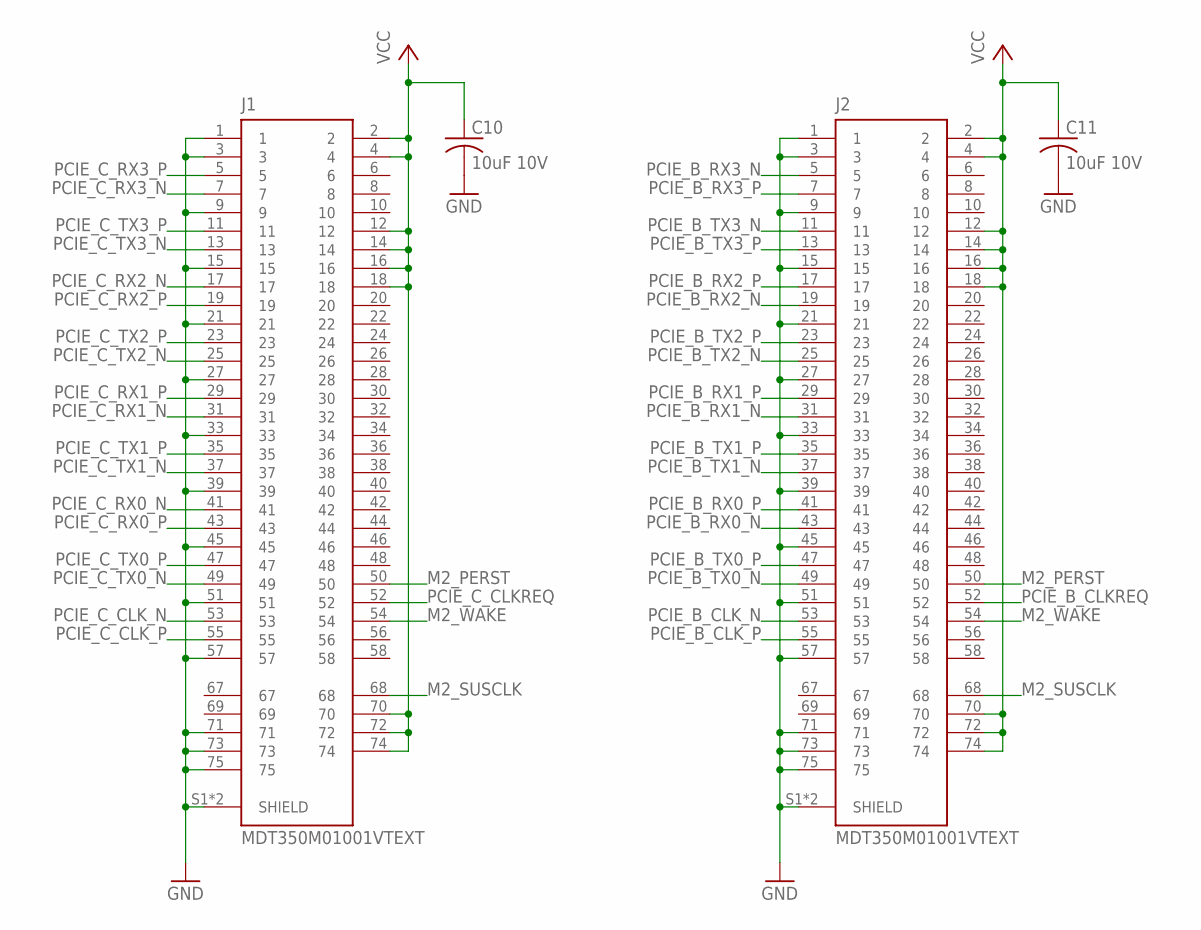
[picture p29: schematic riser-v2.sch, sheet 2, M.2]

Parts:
C10, C11: 10uF 10V; C0603
J1, J2: MDT350M01001VTEXT; MDT350M01001VT_EXT

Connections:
GND: C10.2, C11.2, J1.1, J1.3, J1.9, J1.15, J1.21, J1.27, J1.33, J1.39, J1.45, J1.51, J1.57, J1.71, J1.73, J1.75, J1.S1 (SHIELD), J1.S2 (SHIELD), J2.1, J2.3, J2.9, J2.15, J2.21, J2.27, J2.33, J2.39, J2.45, J2.51, J2.57, J2.71, J2.73, J2.75, J2.S1 (SHIELD), J2.S2 (SHIELD); also elsewhere on the board
M2_PERST: J1.50, J2.50; also elsewhere on the board
M2_SUSCLK: J1.68, J2.68; also elsewhere on the board
M2_WAKE: J1.54, J2.54; also elsewhere on the board
PCIE_B_CLKREQ: J2.52; also elsewhere on the board
PCIE_B_CLK_N: J2.53; also elsewhere on the board
PCIE_B_CLK_P: J2.55; also elsewhere on the board
PCIE_B_RX0_N: J2.43; also elsewhere on the board
PCIE_B_RX0_P: J2.41; also elsewhere on the board
PCIE_B_RX1_N: J2.31; also elsewhere on the board
PCIE_B_RX1_P: J2.29; also elsewhere on the board
PCIE_B_RX2_N: J2.19; also elsewhere on the board
PCIE_B_RX2_P: J2.17; also elsewhere on the board
PCIE_B_RX3_N: J2.5; also elsewhere on the board
PCIE_B_RX3_P: J2.7; also elsewhere on the board
PCIE_B_TX0_N: J2.49; also elsewhere on the board
PCIE_B_TX0_P: J2.47; also elsewhere on the board
PCIE_B_TX1_N: J2.37; also elsewhere on the board
PCIE_B_TX1_P: J2.35; also elsewhere on the board
PCIE_B_TX2_N: J2.25; also elsewhere on the board
PCIE_B_TX2_P: J2.23; also elsewhere on the board
PCIE_B_TX3_N: J2.11; also elsewhere on the board
PCIE_B_TX3_P: J2.13; also elsewhere on the board
PCIE_C_CLKREQ: J1.52; also elsewhere on the board
PCIE_C_CLK_N: J1.53; also elsewhere on the board
PCIE_C_CLK_P: J1.55; also elsewhere on the board
PCIE_C_RX0_N: J1.41; also elsewhere on the board
PCIE_C_RX0_P: J1.43; also elsewhere on the board
PCIE_C_RX1_N: J1.31; also elsewhere on the board
PCIE_C_RX1_P: J1.29; also elsewhere on the board
PCIE_C_RX2_N: J1.17; also elsewhere on the board
PCIE_C_RX2_P: J1.19; also elsewhere on the board
PCIE_C_RX3_N: J1.7; also elsewhere on the board
PCIE_C_RX3_P: J1.5; also elsewhere on the board
PCIE_C_TX0_N: J1.49; also elsewhere on the board
PCIE_C_TX0_P: J1.47; also elsewhere on the board
PCIE_C_TX1_N: J1.37; also elsewhere on the board
PCIE_C_TX1_P: J1.35; also elsewhere on the board
PCIE_C_TX2_N: J1.25; also elsewhere on the board
PCIE_C_TX2_P: J1.23; also elsewhere on the board
PCIE_C_TX3_N: J1.13; also elsewhere on the board
PCIE_C_TX3_P: J1.11; also elsewhere on the board
VCC: C10.1, C11.1, J1.2, J1.4, J1.12, J1.14, J1.16, J1.18, J1.70, J1.72, J1.74, J2.2, J2.4, J2.12, J2.14, J2.16, J2.18, J2.70, J2.72, J2.74; also elsewhere on the board

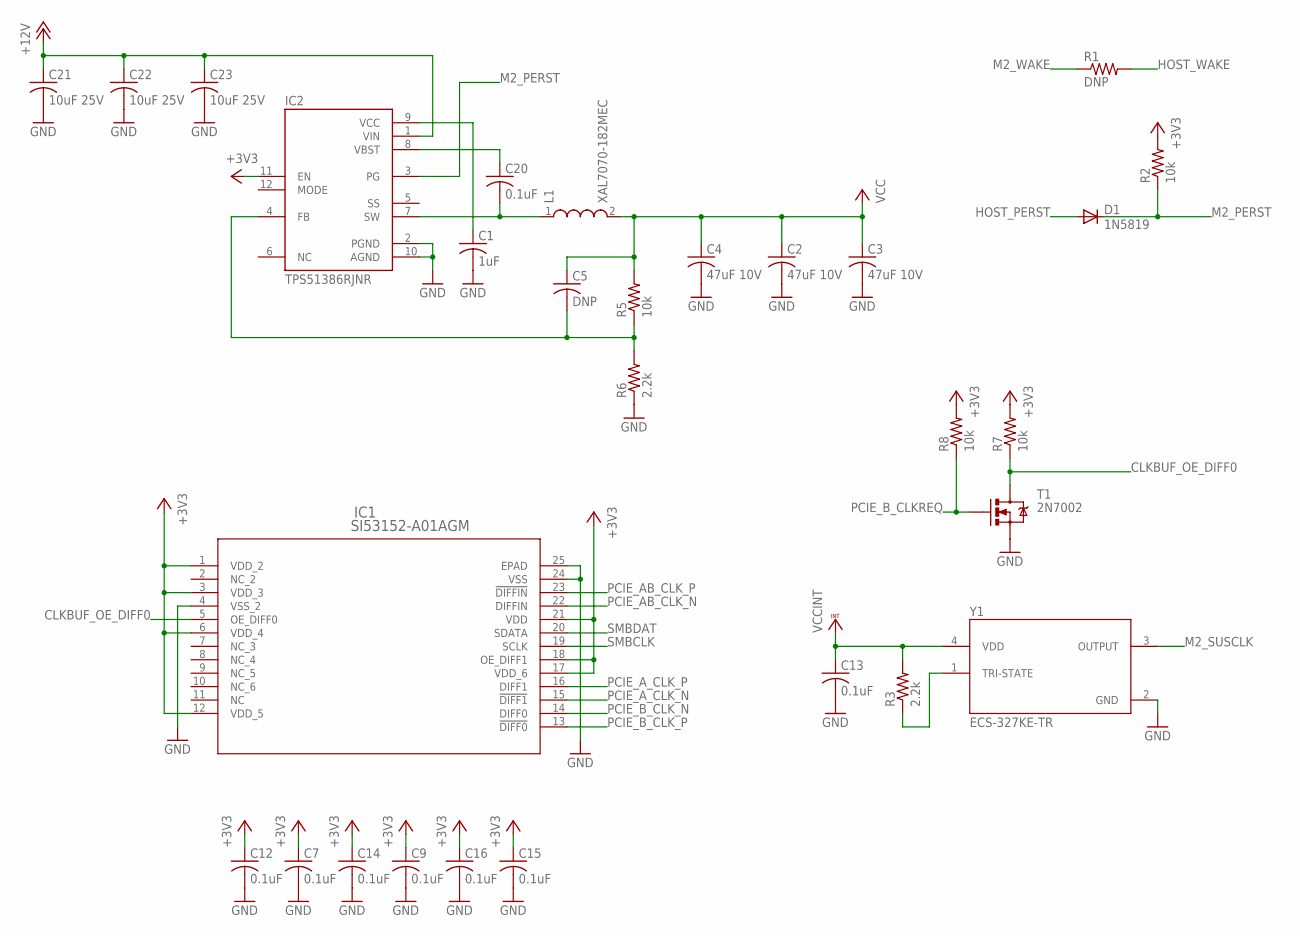
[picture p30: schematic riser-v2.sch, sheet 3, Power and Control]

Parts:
C1: 1uF; C0402
C2, C3, C4: 47uF 10V; C1206
C5: DNP; C0402
C7, C9, C12, C13, C14, C15, C16, C20: 0.1uF; C0402
C21, C22, C23: 10uF 25V; C1206
D1: 1N5819; SOD323-R
IC1: SI53152-A01AGM; QFN24_4X4_SIL
IC2: TPS51386RJNR; VREG_TPS51386RJNR
L1: XAL7070-182MEC; DFN750X725X700-2N; JLC_ROTATION 90
R1: DNP; R0402
R2, R5, R7, R8: 10k; R0402
R3, R6: 2.2k; R0402
T1: 2N7002; SOT23-3; JLC_ROTATION 270
Y1: ECS-327KE-TR; OSC_ECS-327KE-TR

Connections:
+3V3: C7.1, C9.1, C12.1, C14.1, C15.1, C16.1, IC1.1 (VDD_2), IC1.3 (VDD_3), IC1.6 (VDD_4), IC1.12 (VDD_5), IC1.17 (VDD_6), IC1.18 (OE_DIFF1), IC1.21 (VDD), IC2.11 (EN), R2.2, R7.2, R8.2; also elsewhere on the board
+12V: C21.1, C22.1, C23.1, IC2.1 (VIN); also elsewhere on the board
BOOT: C20.1, IC2.8 (VBST)
BUCK_VCC: C1.1, IC2.9 (VCC)
CLKBUF_OE_DIFF0: IC1.5 (OE_DIFF0), R7.1, T1.3 (D)
FB: C5.2, IC2.4 (FB), R5.1, R6.2
GND: C1.2, C2.2, C3.2, C4.2, C7.2, C9.2, C12.2, C13.2, C14.2, C15.2, C16.2, C21.2, C22.2, C23.2, IC1.4 (VSS_2), IC1.24 (VSS), IC1.25 (EPAD), IC2.2 (PGND), IC2.10 (AGND), R6.1, T1.2 (S), Y1.2 (GND); also elsewhere on the board
HOST_PERST: D1.A; also elsewhere on the board
HOST_WAKE: R1.2; also elsewhere on the board
LX: C20.2, IC2.7 (SW), L1.1
M2_PERST: D1.C, IC2.3 (PG), R2.1; also elsewhere on the board
M2_SUSCLK: Y1.3 (OUTPUT); also elsewhere on the board
M2_WAKE: R1.1; also elsewhere on the board
OSC_TRI_STATE: R3.1, Y1.1 (TRI-STATE)
PCIE_AB_CLK_N: IC1.22 (DIFFIN); also elsewhere on the board
PCIE_AB_CLK_P: IC1.23 (!DIFFIN); also elsewhere on the board
PCIE_A_CLK_N: IC1.15 (!DIFF1); also elsewhere on the board
PCIE_A_CLK_P: IC1.16 (DIFF1); also elsewhere on the board
PCIE_B_CLKREQ: R8.1, T1.1 (G); also elsewhere on the board
PCIE_B_CLK_N: IC1.14 (DIFF0); also elsewhere on the board
PCIE_B_CLK_P: IC1.13 (!DIFF0); also elsewhere on the board
SMBCLK: IC1.19 (SCLK); also elsewhere on the board
SMBDAT: IC1.20 (SDATA); also elsewhere on the board
VCC: C2.1, C3.1, C4.1, C5.1, L1.2, R5.2; also elsewhere on the board
VCCINT: C13.1, R3.2, Y1.4 (VDD); also elsewhere on the board

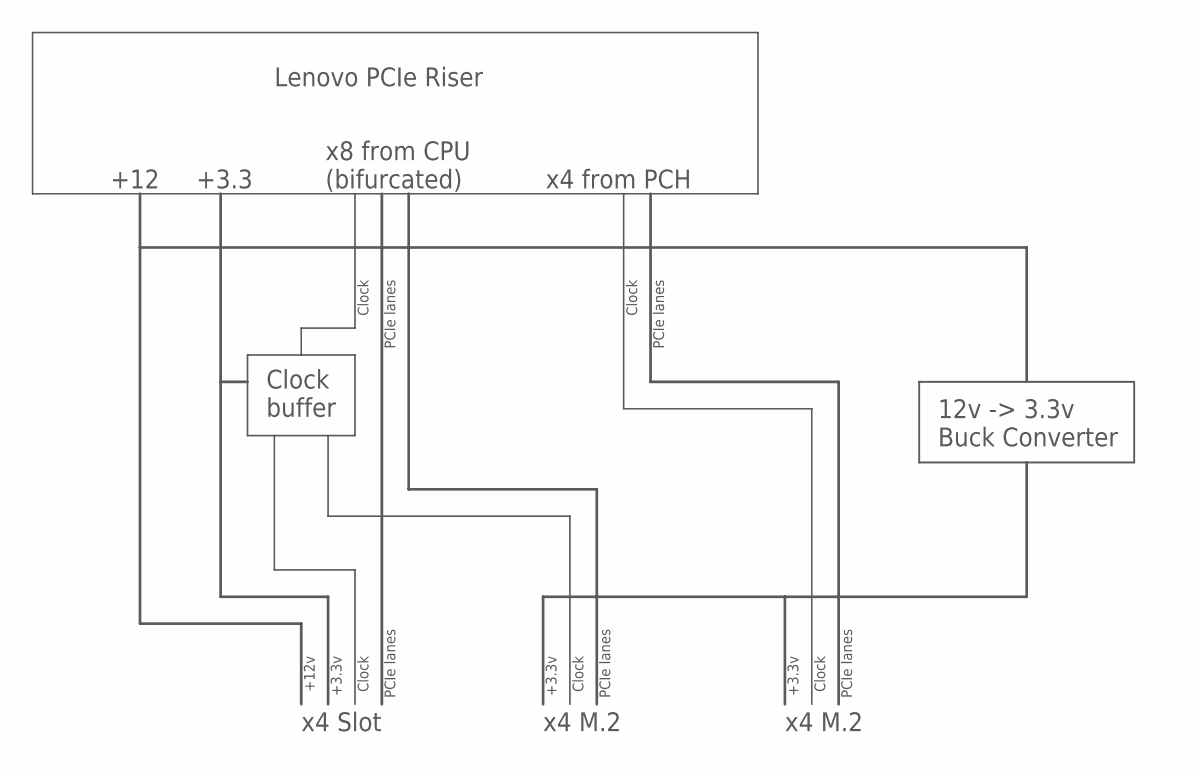
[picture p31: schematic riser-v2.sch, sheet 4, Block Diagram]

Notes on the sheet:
Lenovo PCIe Riser
x8 from CPU (bifurcated)
x4 from PCH
+12 +3.3
Clock buffer
x4 Slot
x4 M.2
12v -> 3.3v Buck Converter
PCIe lanes
Clock
+3.3v
+12v

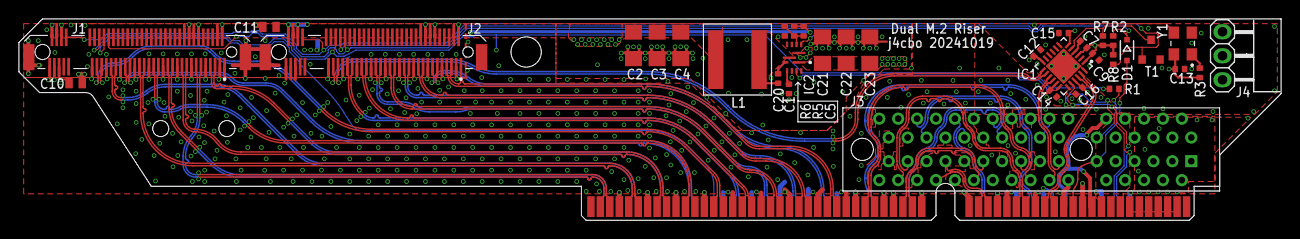
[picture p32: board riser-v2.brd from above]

Board: 4 copper layers, 133.5 x 21.3 mm, 36 parts (0 on the bottom side), 76 nets.

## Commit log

2024-04-06 Add power supply info
2024-05-14 Production boards are in
2024-05-14 Add mounting hardware
    [m2-mount.stl, pcb-angle.stl, spacer.stl]
2024-06-04 Add PCB files
    [riser-bom.csv, riser.brd, riser.sch]
2024-06-20 Add resistor diagram
2025-01-18 Add V2 PCB
    [riser-v2.GBL, riser-v2.GBO, riser-v2.GBP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]
2025-01-18 Add schematic
2025-02-27 add more mount options
    [m2-mount_2230_2280.stl, m2-mount_2x2230.stl]
2025-03-13 Do not place C5
    This was an error - see https://github.com/j4cbo/tiny5-m2-riser/issues/15
    [riser-v2.brd, riser-v2_top_bom.csv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]
2025-03-13 Mark DNP in EAGLE files too
    [riser-v2.brd, riser-v2.sch]
2025-07-16 Update riser-v2_top_bom.csv
    Fixed JLPCB part numbers and removed duplicate part number for C10/C11
    [riser-v2_top_bom.csv]
2025-11-03 Added impendance control Excel file and updated Gerber zip with this file
    [Required_impedance_control.xlsx]
2025-11-03 Revise PCB assembly instructions in README
    Updated PCB assembly options and requirements in README.

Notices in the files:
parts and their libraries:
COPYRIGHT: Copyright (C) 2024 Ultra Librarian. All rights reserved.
